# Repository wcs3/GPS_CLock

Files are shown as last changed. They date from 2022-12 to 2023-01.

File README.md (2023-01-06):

# GPS_CLock

A device that displays time and date on 7-segment displays in ISO8601 format.

Features:
 - Retrieves accurate time from GPS satellites
 - Displays time in compliance with ISO8601
 - Powered from a rechargeable battery for portable usage
 - Charges from a power delivery capable USB Type-C port

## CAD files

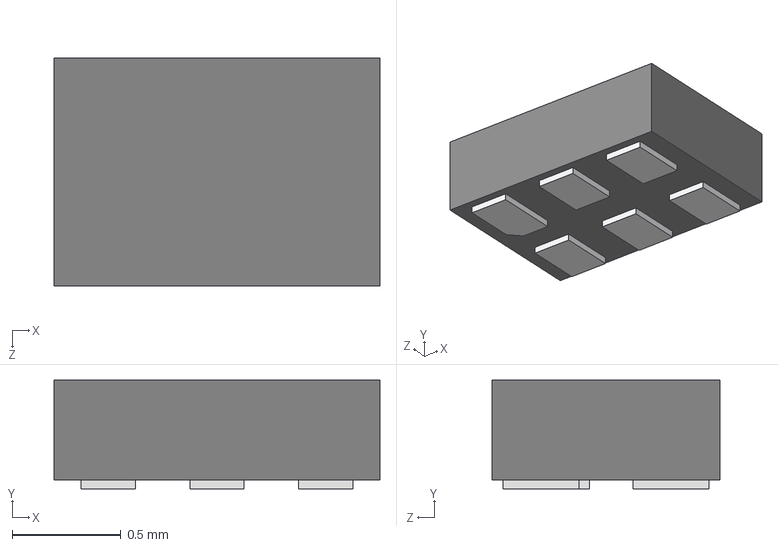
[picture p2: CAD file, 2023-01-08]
kicad/3d/SOT886.step
1.50 x 0.5 x 1.05 mm

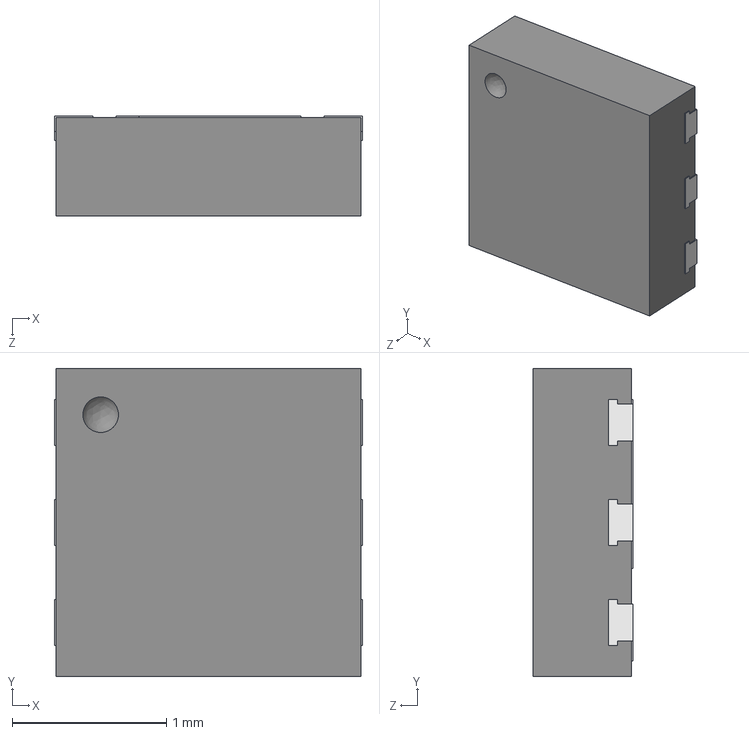
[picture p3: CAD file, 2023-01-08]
kicad/3d/User Library-PMPB95ENEA.STEP
2.00 x 2.00 x 0.65 mm

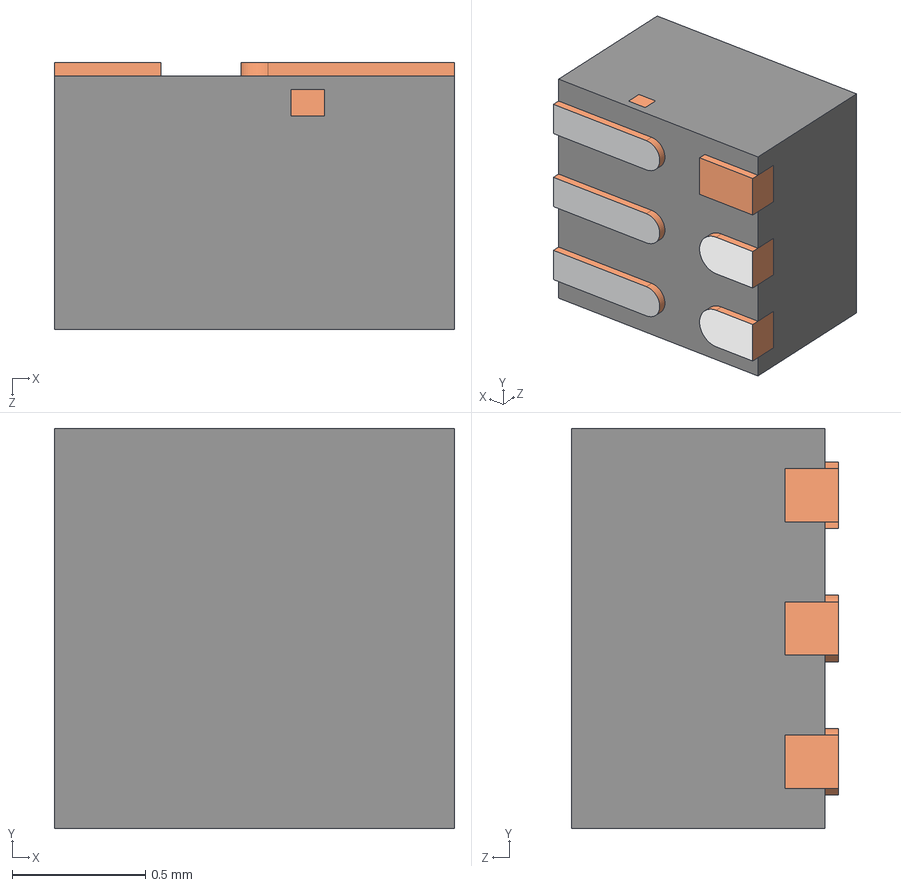
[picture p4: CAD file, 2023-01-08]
kicad/3d/VSON-HR-6.STEP
1.50 x 1.50 x 1.00 mm
BODY-SON
FRAME-DMQ0006A

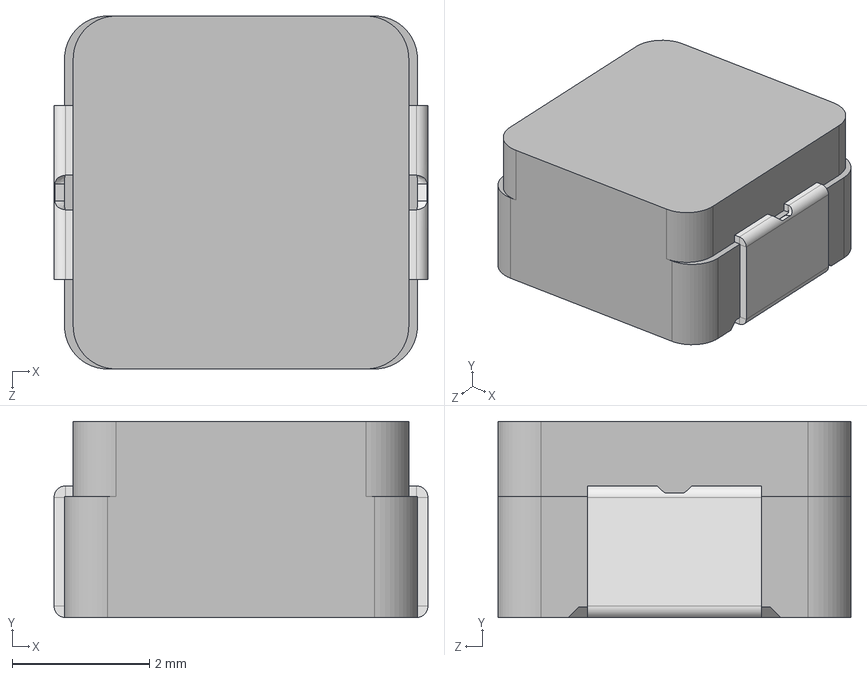
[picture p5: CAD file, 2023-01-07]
kicad/3d/IHLP2020CZ.STEP
5.45 x 2.86 x 5.15 mm

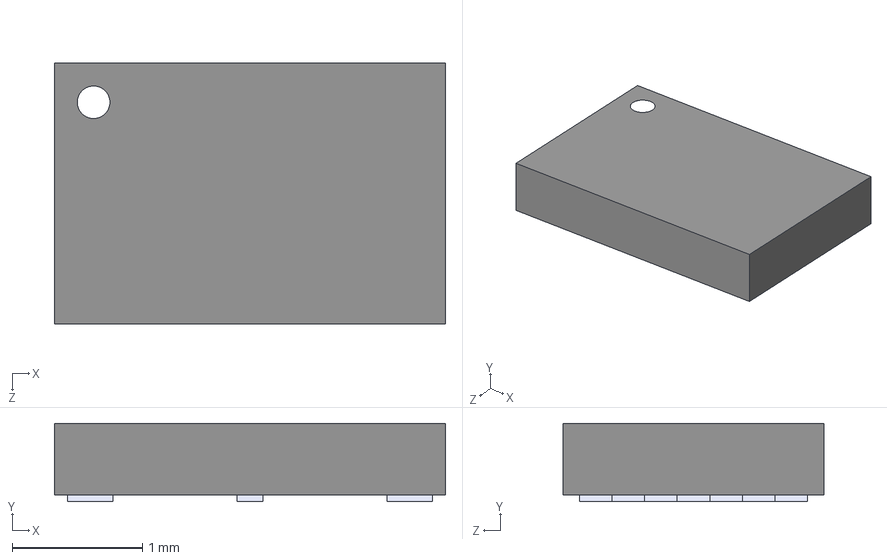
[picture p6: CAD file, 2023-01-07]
kicad/3d/W25Q16JVUXIQ.STEP
3.00 x 0.6 x 2.00 mm

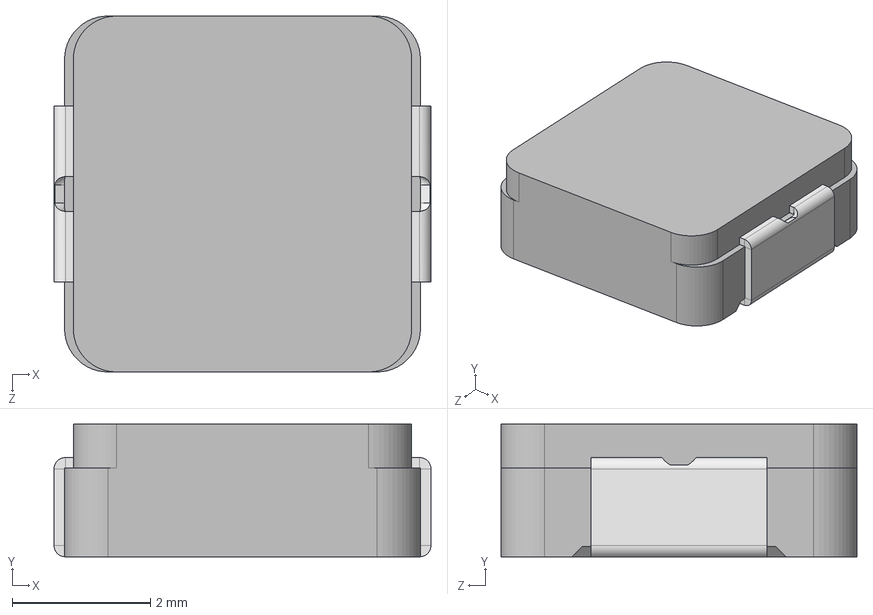
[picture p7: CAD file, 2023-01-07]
kicad/3d/IHLP2020BZ.STEP
5.45 x 1.92 x 5.15 mm

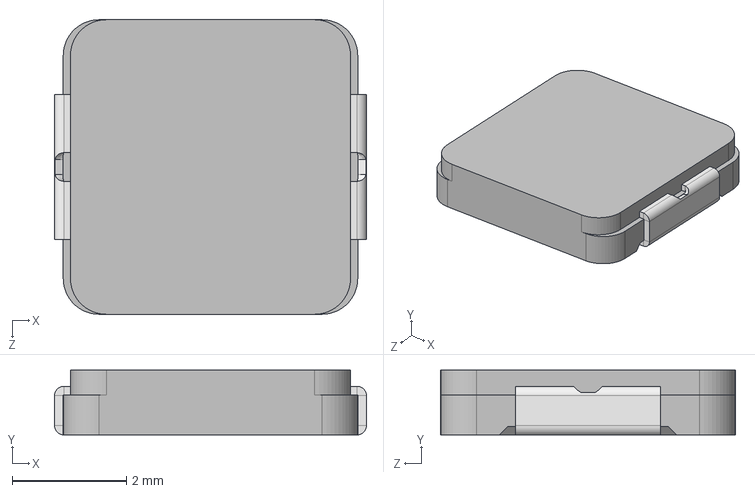
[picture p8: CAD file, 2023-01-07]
kicad/3d/IHLP2020AB.STEP
5.45 x 1.14 x 5.15 mm

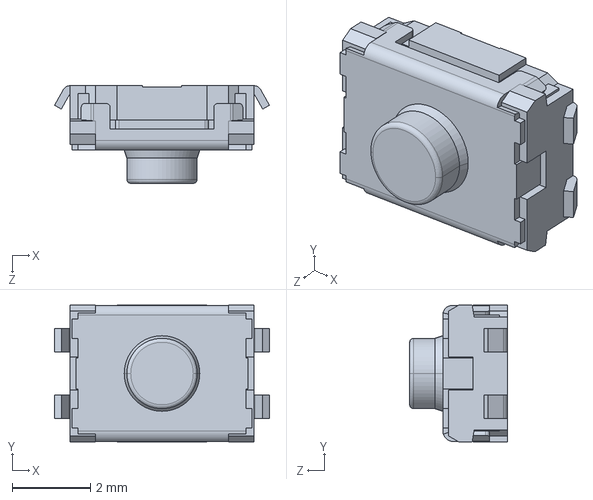
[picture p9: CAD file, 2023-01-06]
kicad/3d/EVQ-P2-H02B_K02Q+3P202K.STEP
5.50 x 3.50 x 2.50 mm

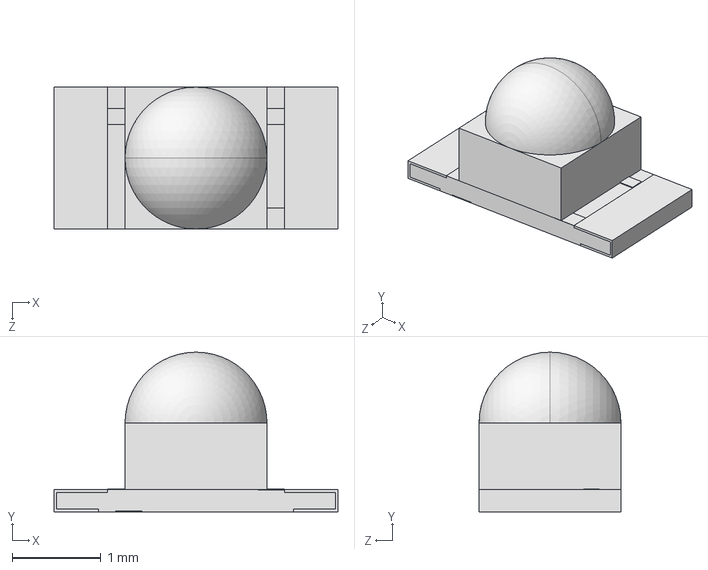
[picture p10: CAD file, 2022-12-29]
kicad/3d/APTD3216.STEP
3.20 x 1.80 x 1.60 mm

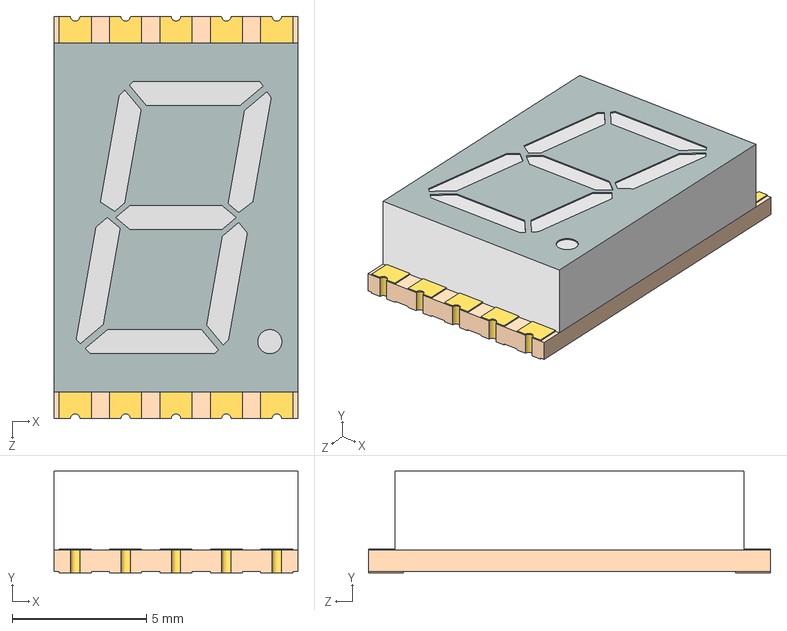
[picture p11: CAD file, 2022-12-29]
kicad/3d/ACSX04-41.STEP
9.10 x 3.80 x 15.0 mm

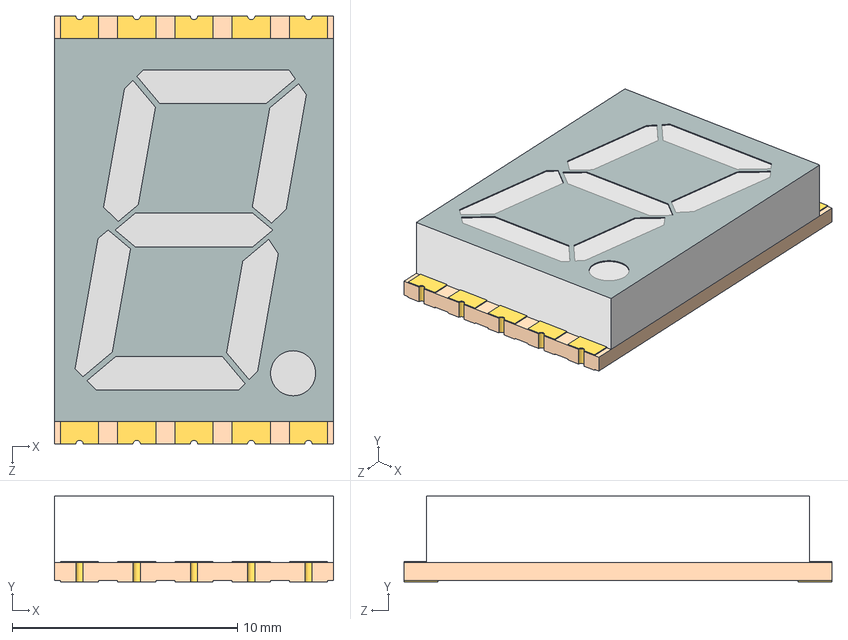
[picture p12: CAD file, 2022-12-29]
kicad/3d/ACSX56-41.STEP
12.4 x 3.80 x 19.0 mm

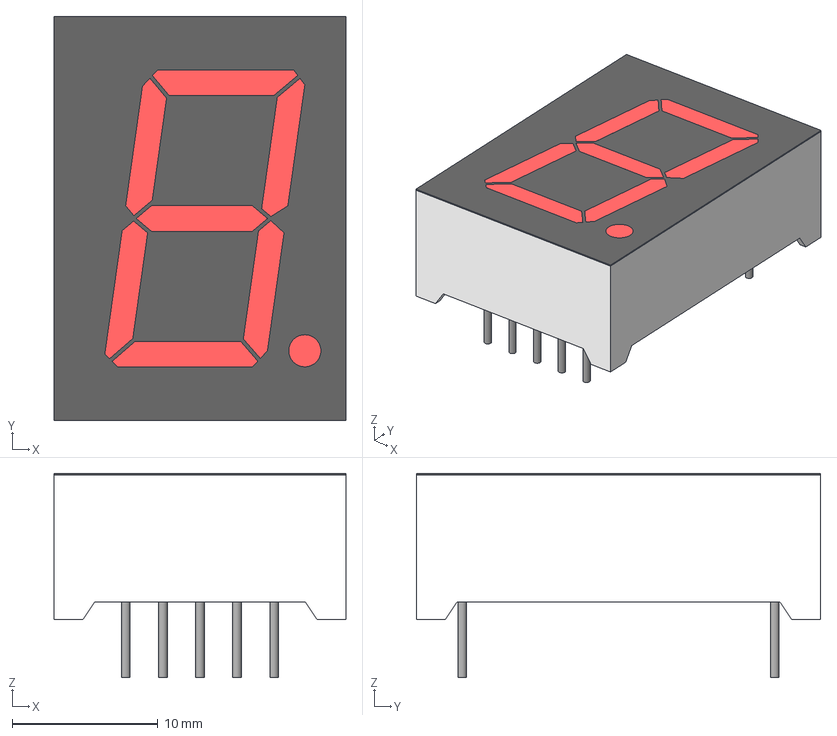
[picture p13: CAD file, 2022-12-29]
kicad/3d/7 seg 0,8 inch.step
20.0 x 27.7 x 14.0 mm

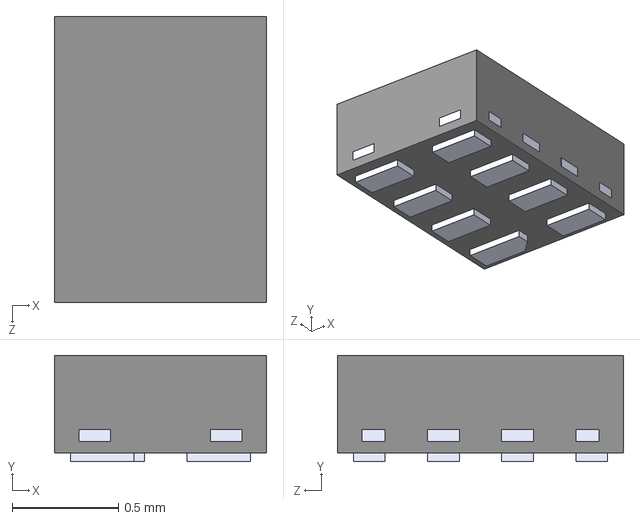
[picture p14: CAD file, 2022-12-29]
kicad/3d/74LVC3G17GS_115.step
1.00 x 0.5 x 1.35 mm

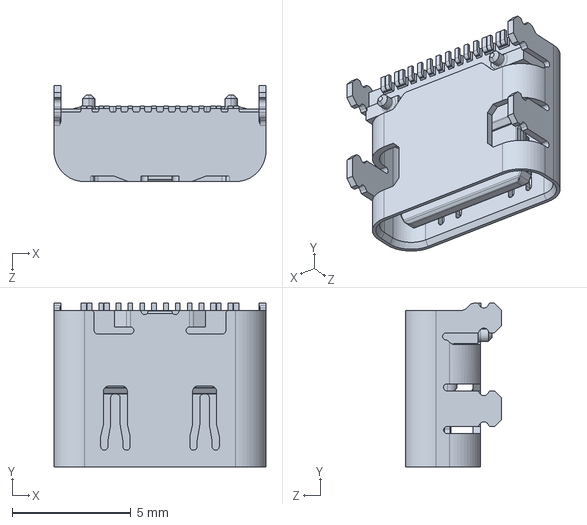
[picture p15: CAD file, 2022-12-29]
kicad/3d/K3D-DX07S016JA1-V1_JAE_Proprietary.STEP
8.94 x 6.90 x 4.06 mm

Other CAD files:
kicad/3d/MAX-M8C-0-10--3DModel-STEP-56544.STEP
kicad/3d/ACPSX04-41.STEP
kicad/3d/TactileSw6x6x4.3.STEP
kicad/3d/1-1734839-6.step
kicad/3d/14-Segment_0.4in_SMD.step
kicad/3d/7-Segment_0.4in_SMD.step
kicad/3d/84592VEML7700.stp
kicad/3d/ACSX08-51.STEP
kicad/3d/DFE201610P-R47M=P2.STEP
kicad/3d/EVQP4-HB3B_KB3Q_MB3K.STEP
kicad/3d/FH35-21S-0.3SHW.stp
kicad/3d/MS860702BA01-50--3DModel-STEP-1.STEP
kicad/3d/PSON30P120X100X35-8N.step

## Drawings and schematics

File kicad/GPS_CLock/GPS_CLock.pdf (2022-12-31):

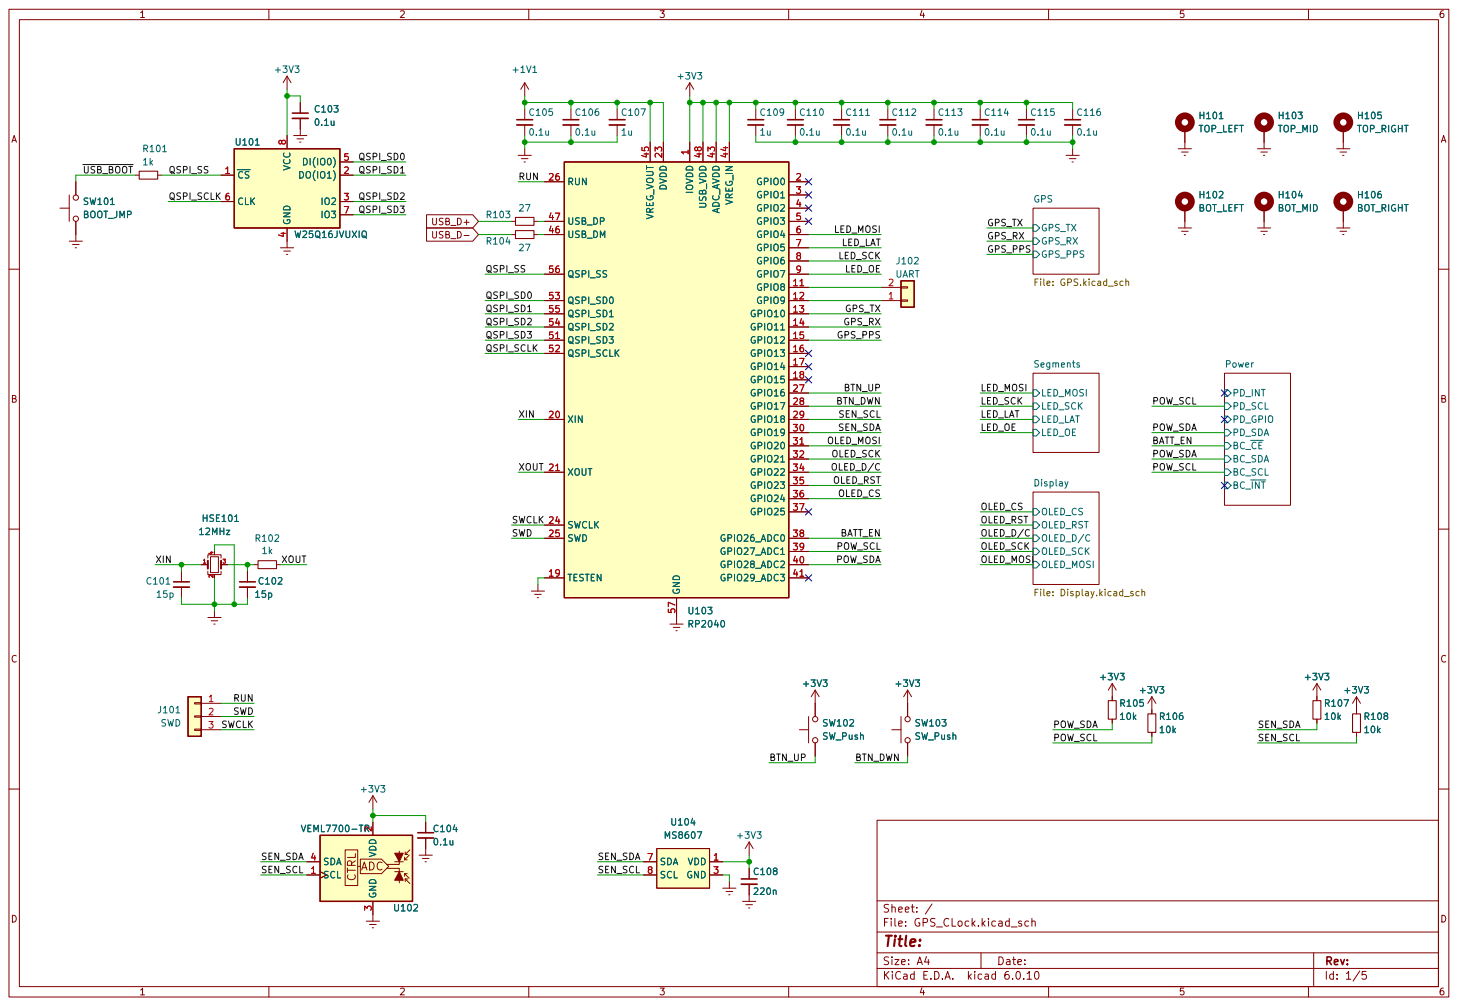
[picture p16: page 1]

1 GPIO8 11 GPIO9 12 GPIO10 13 GPIO11 14 GPIO12 15 GPIO13 16 GPIO14 17 GPIO15 18 TESTEN 19 GPIO0 2 XIN 20 XOUT 21 DVDD 23 SWCLK 24 SWD 25 RUN 26 GPIO16 27 GPIO17 28 GPIO18 29 GPIO1 3 GPIO19 30 GPIO20 31 GPIO21 32 GPIO22 34 GPIO23 35 GPIO24 36 GPIO25 37 GPIO26_ADC0 38 GPIO27_ADC1 39 GPIO2 4 GPIO28_ADC2 40 GPIO29_ADC3 41 ADC_AVDD 43 VREG_IN 44 VREG_VOUT 45 USB_DM 46 USB_DP 47 USB_VDD 48 GPIO3 5 QSPI_SD3 51 QSPI_SCLK 52 QSPI_SD0 53 QSPI_SD2 54 QSPI_SD1 55 QSPI_SS 56 GND 57 GPIO4 6 GPIO5 7 GPIO6 8 GPIO7 9 C102

1 GPIO8 11 GPIO9 12 GPIO10 13 GPIO11 14 GPIO12 15 GPIO13 16 GPIO14 17 GPIO15 18 TESTEN 19 GPIO0 2 XIN 20 XOUT 21 DVDD 23 SWCLK 24 SWD 25 RUN 26 GPIO16 27 GPIO17 28 GPIO18 29 GPIO1 3 GPIO19 30 GPIO20 31 GPIO21 32 GPIO22 34 GPIO23 35 GPIO24 36 GPIO25 37 GPIO26_ADC0 38 GPIO27_ADC1 39 GPIO2 4 GPIO28_ADC2 40 GPIO29_ADC3 41 ADC_AVDD 43 VREG_IN 44 VREG_VOUT 45 USB_DM 46 USB_DP 47 USB_VDD 48 GPIO3 5 QSPI_SD3 51 QSPI_SCLK 52 QSPI_SD0 53 QSPI_SD2 54 QSPI_SD1 55 QSPI_SS 56 GND 57 GPIO4 6 GPIO5 7 GPIO6 8 GPIO7 9 U103 RP2040

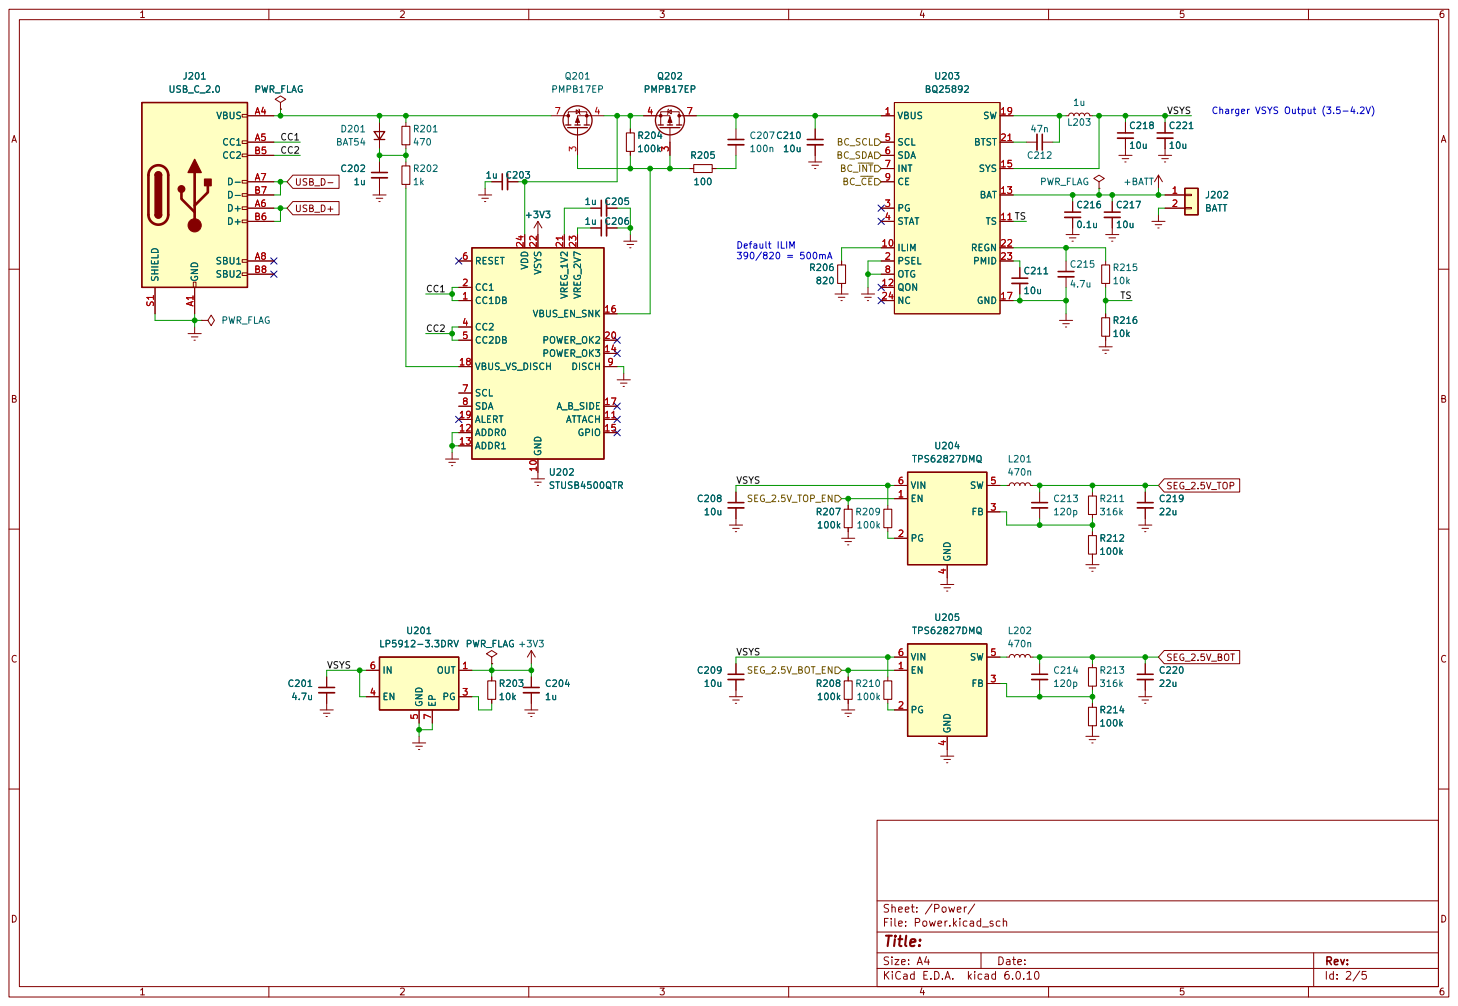
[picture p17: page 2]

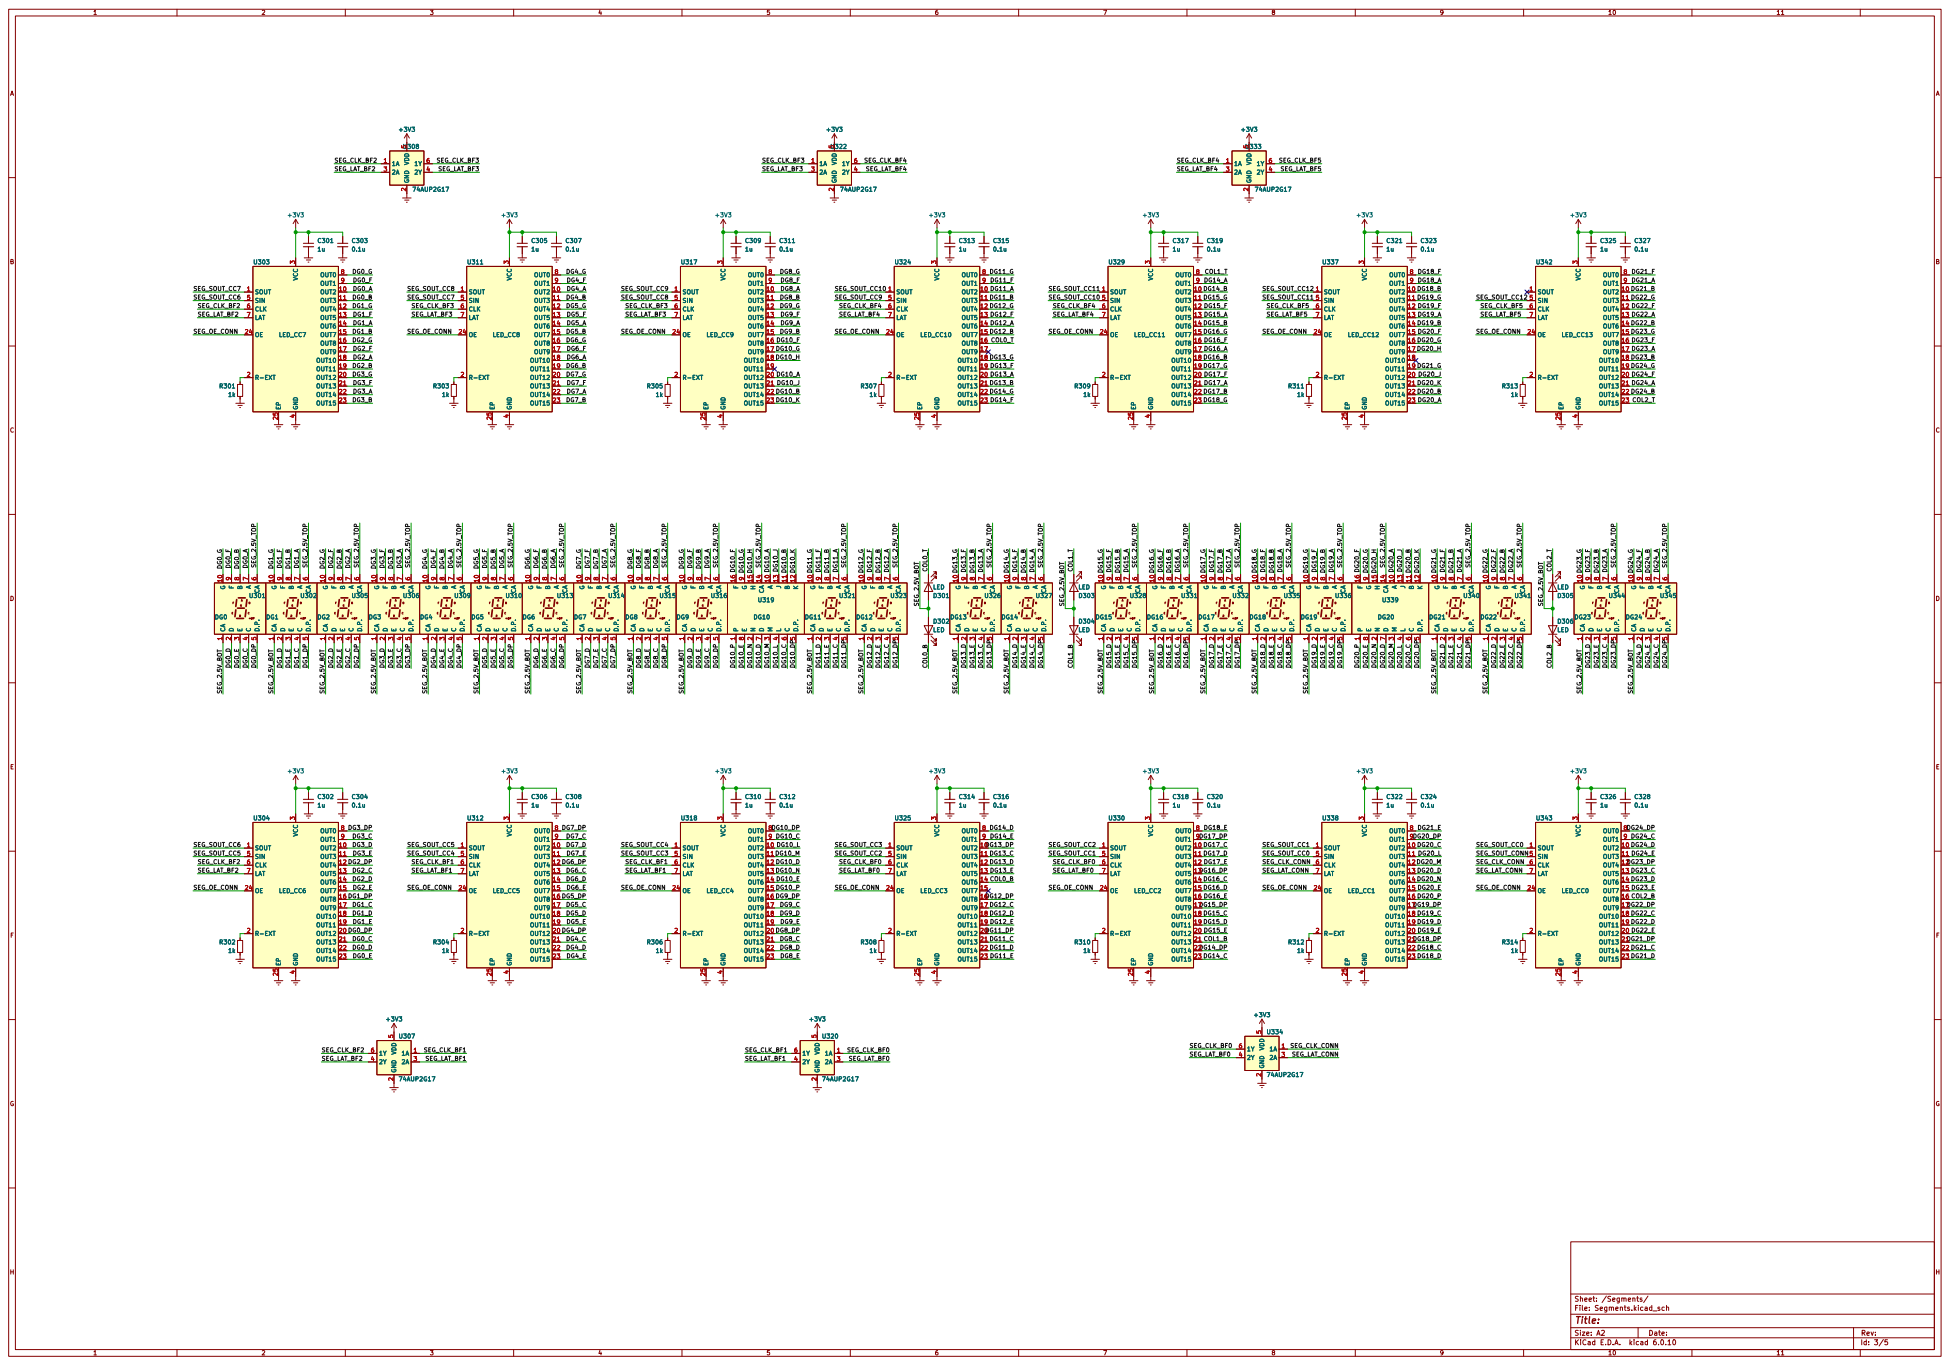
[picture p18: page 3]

9 U301 DG0 SOUT 1 OUT2 10 OUT3 11 OUT4 12 OUT5 13 OUT6 14 OUT7 15 OUT8 16 OUT9 17 OUT10 18 OUT11 19 R-EXT 2 OUT12 20 OUT13 21 OUT14 22 OUT15 23 OE 24 EP 25 VCC

9 U316 DG9SOUT 1 OUT2 10 OUT3 11 OUT4 12 OUT5 13 OUT6 14 OUT7 15 OUT8 16 OUT9 17 OUT10 18 OUT11 19 R-EXT 2 OUT12 20 OUT13 21 OUT14 22 OUT15 23 OE 24 EP 25 VCC

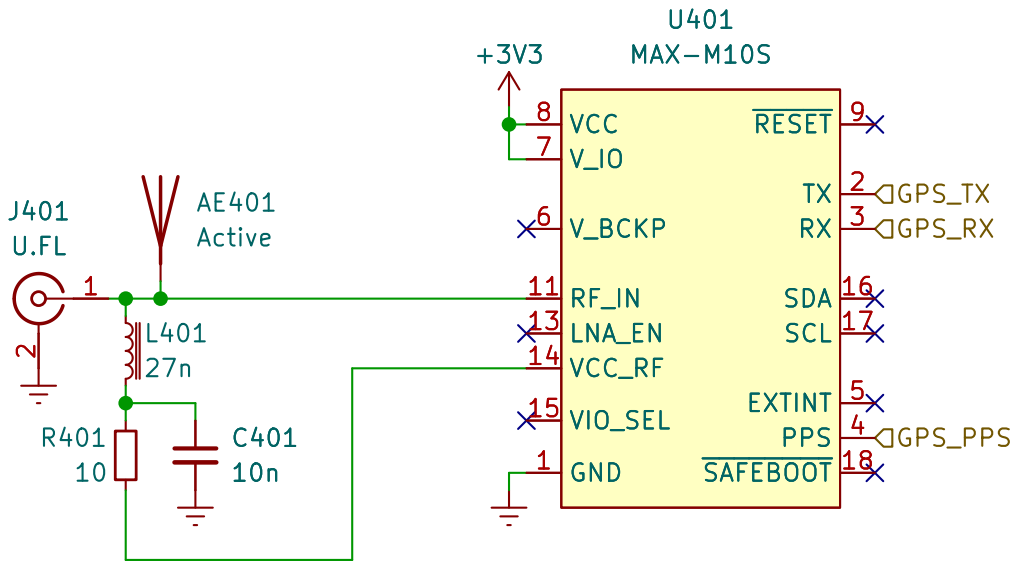
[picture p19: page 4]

File: GPS.kicad_sch Sheet: /GPS/
Id: 5/5 Title:

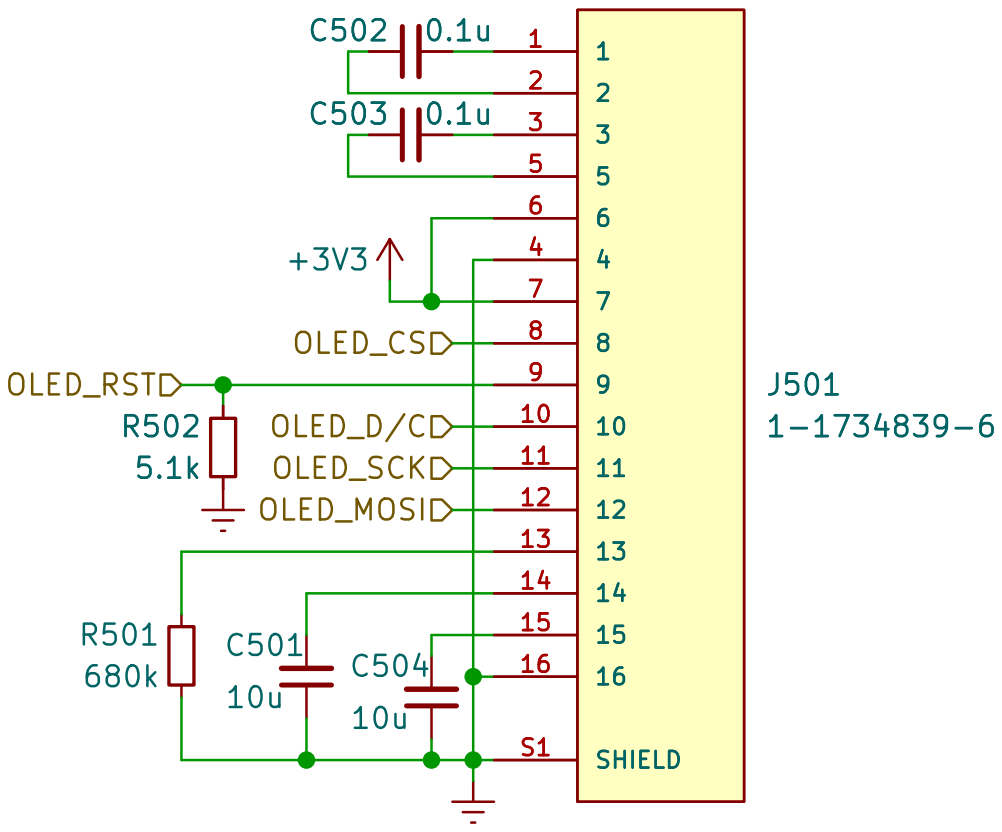
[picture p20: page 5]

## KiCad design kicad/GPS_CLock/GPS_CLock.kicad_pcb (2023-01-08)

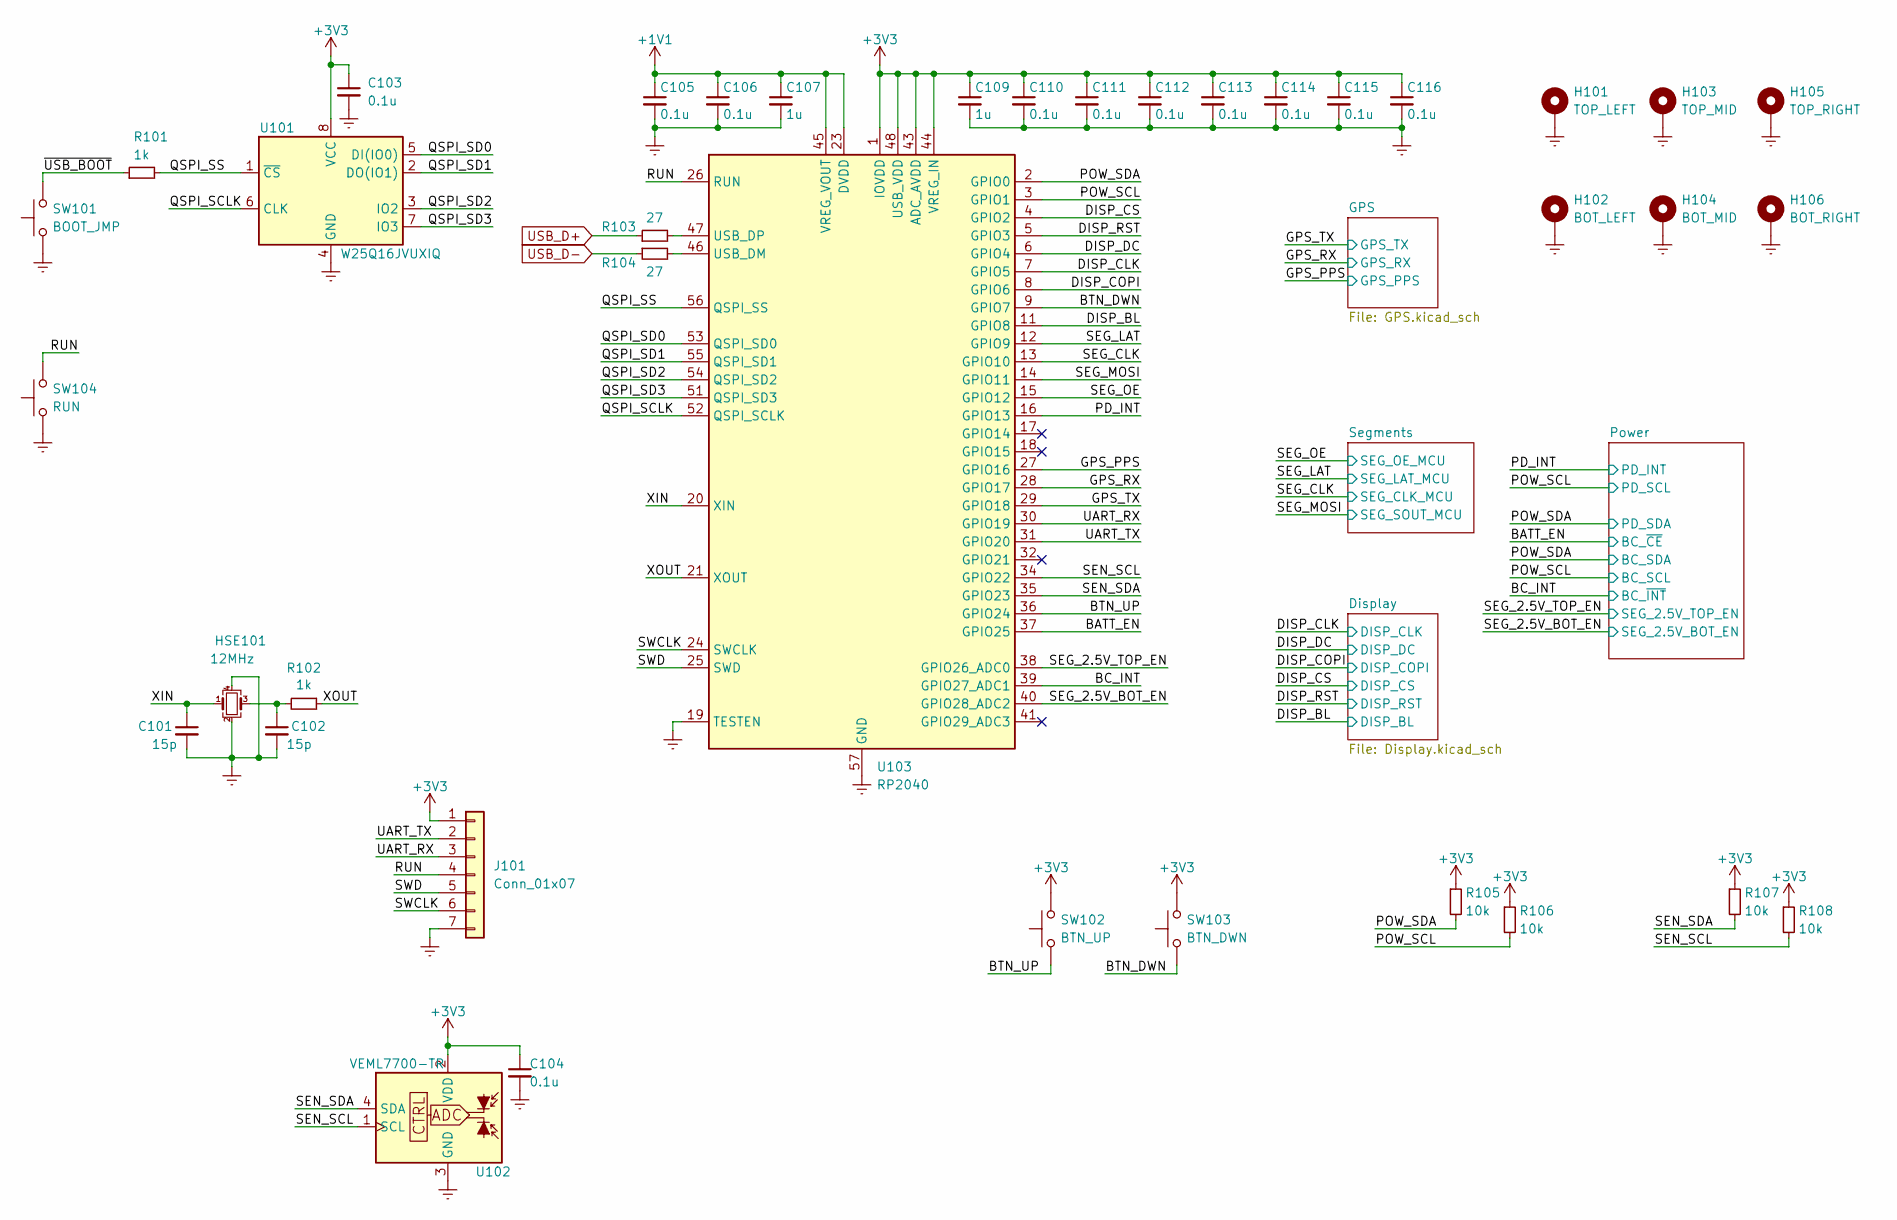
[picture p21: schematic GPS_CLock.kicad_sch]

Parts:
C101, C102: 15p; C_0402_1005Metric
C103, C104, C105, C106, C110, C111, C112, C113, C114, C115, C116: 0.1u; C_0402_1005Metric
C107, C109: 1u; C_0402_1005Metric
H101: TOP_LEFT; MountingHole_3.2mm_M3_DIN965_Pad
H102: BOT_LEFT; MountingHole_3.2mm_M3_DIN965_Pad
H103: TOP_MID; MountingHole_3.2mm_M3_DIN965_Pad
H104: BOT_MID; MountingHole_3.2mm_M3_DIN965_Pad
H105: TOP_RIGHT; MountingHole_3.2mm_M3_DIN965_Pad
H106: BOT_RIGHT; MountingHole_3.2mm_M3_DIN965_Pad
HSE101: 12MHz; Crystal_SMD_3225-4Pin_3.2x2.5mm
J101: Conn_01x07; PinHeader_1x07_P1.27mm_Vertical
R101, R102: 1k; R_0402_1005Metric
R103, R104: 27; R_0402_1005Metric
R105, R106, R107, R108: 10k; R_0402_1005Metric
SW101: BOOT_JMP; SW_SPST_EVQP2
SW102: BTN_UP; SW_SPST_EVQP2
SW103: BTN_DWN; SW_SPST_EVQP2
SW104: RUN; SW_SPST_EVQP2
U101: W25Q16JVUXIQ; WINBOND_USON-8_2x3mm
U102: VEML7700-TR; VEML7700
U103: RP2040; QFN-56-1EP_7x7mm_P0.4mm_EP3.2x3.2mm

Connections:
+1V1: C105.1, C106.1, C107.1, U103.23 (DVDD), U103.45 (VREG_VOUT), U103.50 (DVDD)
+3V3: C103.1, C104.1, C109.1, C110.1, C111.1, C112.1, C113.1, C114.1, C115.1, C116.1, J101.1, R105.1, R106.1, R107.1, R108.1, SW102.1, SW103.1, U101.8 (VCC), U102.2 (VDD), U103.1 (IOVDD), U103.10 (IOVDD), U103.22 (IOVDD), U103.33 (IOVDD), U103.42 (IOVDD), U103.43 (ADC_AVDD), U103.44 (VREG_IN), U103.48 (USB_VDD), U103.49 (IOVDD); also elsewhere on the board
/BATT_EN: U103.37 (GPIO25); also elsewhere on the board
/BC_INT: U103.39 (GPIO27_ADC1); also elsewhere on the board
/BTN_DWN: SW103.2, U103.9 (GPIO7)
/BTN_UP: SW102.2, U103.36 (GPIO24)
/DISP_BL: U103.11 (GPIO8); also elsewhere on the board
/DISP_CLK: U103.7 (GPIO5); also elsewhere on the board
/DISP_COPI: U103.8 (GPIO6); also elsewhere on the board
/DISP_CS: U103.4 (GPIO2); also elsewhere on the board
/DISP_DC: U103.6 (GPIO4); also elsewhere on the board
/DISP_RST: U103.5 (GPIO3); also elsewhere on the board
/GPS_PPS: U103.27 (GPIO16); also elsewhere on the board
/GPS_RX: U103.28 (GPIO17); also elsewhere on the board
/GPS_TX: U103.29 (GPIO18); also elsewhere on the board
/PD_INT: U103.16 (GPIO13); also elsewhere on the board
/POW_SCL: R106.2, U103.3 (GPIO1); also elsewhere on the board
/POW_SDA: R105.2, U103.2 (GPIO0); also elsewhere on the board
/QSPI_SCLK: U101.6 (CLK), U103.52 (QSPI_SCLK)
/QSPI_SD0: U101.5 (DI(IO0)), U103.53 (QSPI_SD0)
/QSPI_SD1: U101.2 (DO(IO1)), U103.55 (QSPI_SD1)
/QSPI_SD2: U101.3 (IO2), U103.54 (QSPI_SD2)
/QSPI_SD3: U101.7 (IO3), U103.51 (QSPI_SD3)
/QSPI_SS: R101.2, U101.1 (~CS), U103.56 (QSPI_SS)
/RUN: J101.4, SW104.1, U103.26 (RUN)
/SEG_2.5V_BOT_EN: U103.40 (GPIO28_ADC2); also elsewhere on the board
/SEG_2.5V_TOP_EN: U103.38 (GPIO26_ADC0); also elsewhere on the board
/SEG_CLK: U103.13 (GPIO10); also elsewhere on the board
/SEG_LAT: U103.12 (GPIO9); also elsewhere on the board
/SEG_MOSI: U103.14 (GPIO11); also elsewhere on the board
/SEG_OE: U103.15 (GPIO12); also elsewhere on the board
/SEN_SCL: R108.2, U102.1 (SCL), U103.34 (GPIO22)
/SEN_SDA: R107.2, U102.4 (SDA), U103.35 (GPIO23)
/SWCLK: J101.6, U103.24 (SWCLK)
/SWD: J101.5, U103.25 (SWD)
/UART_RX: J101.3, U103.30 (GPIO19)
/UART_TX: J101.2, U103.31 (GPIO20)
/XIN: C101.1, HSE101.1, U103.20 (XIN)
/XOUT: R102.1, U103.21 (XOUT)
/~USB_BOOT: R101.1, SW101.1
Earth: C101.2, C102.2, C103.2, C104.2, C105.2, C106.2, C107.2, C109.2, C110.2, C111.2, C112.2, C113.2, C114.2, C115.2, C116.2, H101.1, H102.1, H103.1, H104.1, H105.1, H106.1, HSE101.2, HSE101.4, J101.7, SW101.2, SW104.2, U101.4 (GND), U102.3 (GND), U103.19 (TESTEN), U103.57 (GND); also elsewhere on the board
unnamed: C102.1, HSE101.3, R102.2
unnamed: R103.2, U103.47 (USB_DP)
unnamed: R104.2, U103.46 (USB_DM)
USB_D+: R103.1; also elsewhere on the board
USB_D-: R104.1; also elsewhere on the board

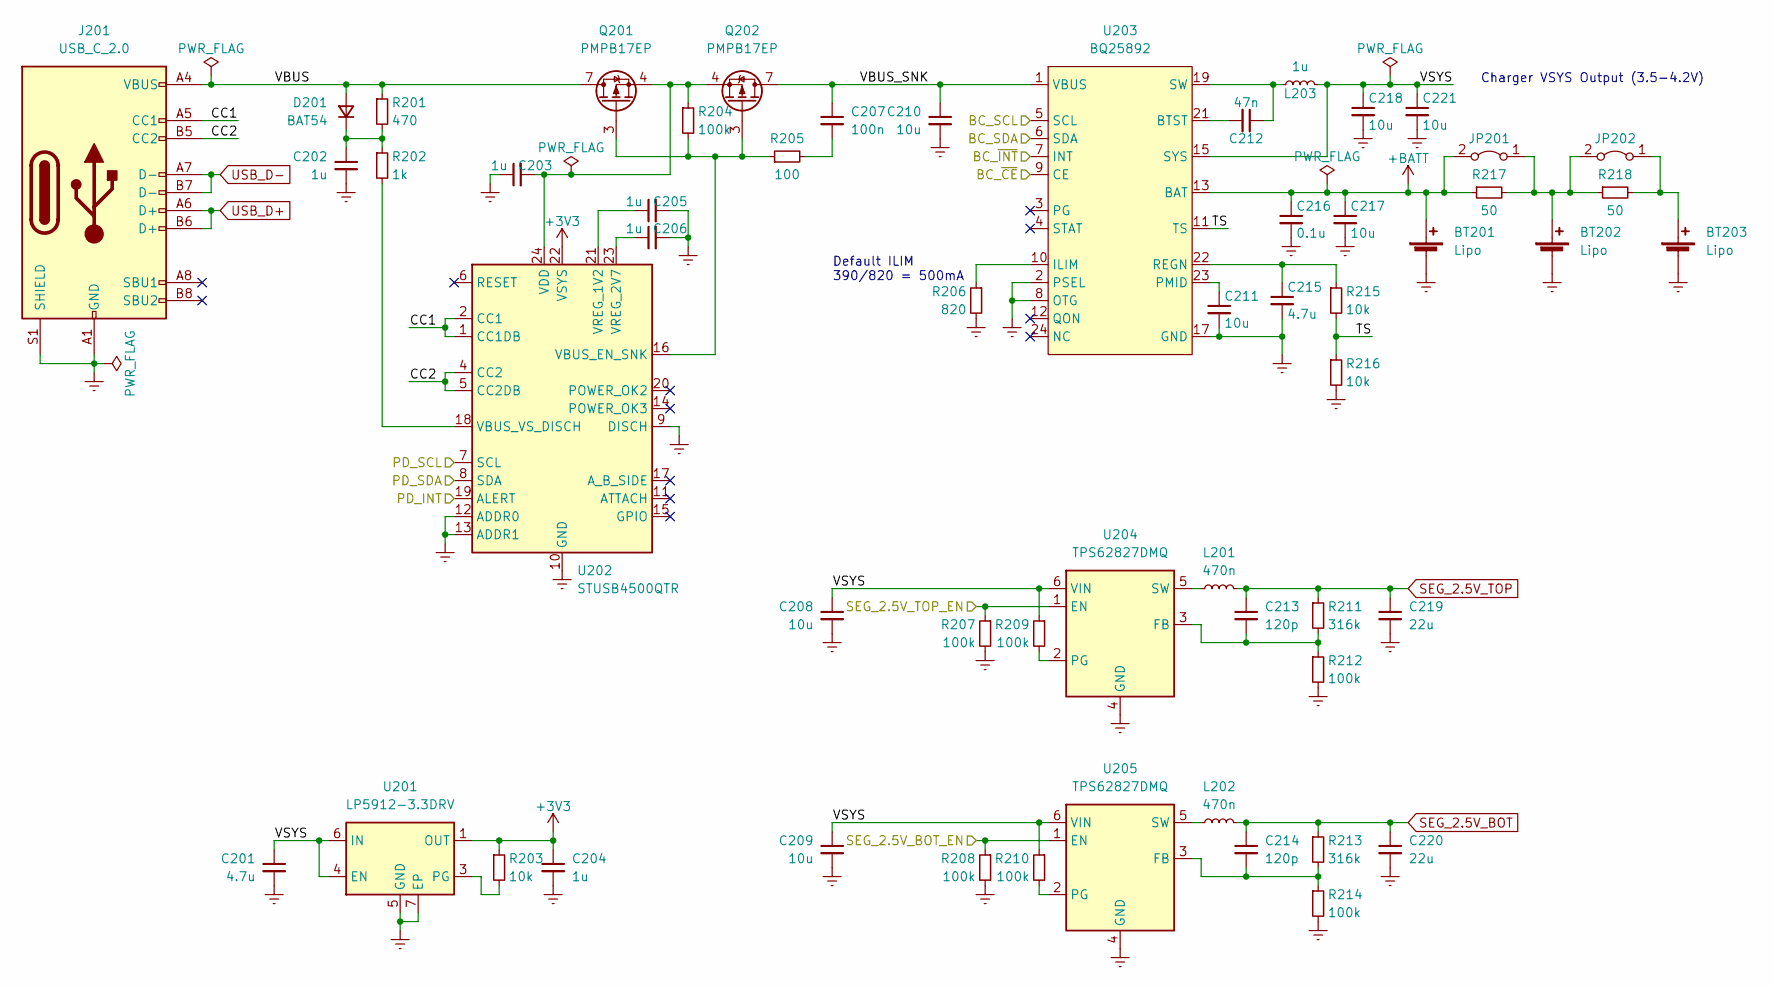
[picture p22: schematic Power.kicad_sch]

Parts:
BT201, BT202, BT203: Lipo; JST_PH_S2B-PH-K_1x02_P2.00mm_Horizontal
C201: 4.7u; C_0603_1608Metric
C202, C203, C204, C205, C206: 1u; C_0402_1005Metric
C207: 100n; C_0402_1005Metric
C208, C209, C217, C218, C221: 10u; C_0603_1608Metric
C210, C211: 10u; C_0402_1005Metric
C212: 47n; C_0402_1005Metric
C213, C214: 120p; C_0402_1005Metric
C215: 4.7u; C_0402_1005Metric
C216: 0.1u; C_0402_1005Metric
C219, C220: 22u; C_0603_1608Metric
D201: BAT54; D_SOD-323
J201: USB_C_2.0; USB_C_Receptacle_JAE_DX07S016JA1R1500
JP201, JP202: Jumper_2_Bridged; PinHeader_1x02_P2.54mm_Horizontal
L201, L202: 470n; L_DFE201610
L203: 1u; L_Vishay_IHLP-2020
Q201, Q202: PMPB17EP; NXP_DFN6_2.0x2.0mm 2xEp
R201: 470; R_0402_1005Metric
R202: 1k; R_0402_1005Metric
R203, R215, R216: 10k; R_0402_1005Metric
R204, R207, R208, R209, R210, R212, R214: 100k; R_0402_1005Metric
R205: 100; R_0402_1005Metric
R206: 820; R_0402_1005Metric
R211, R213: 316k; R_0402_1005Metric
R217, R218: 50; R_1206_3216Metric
U201: LP5912-3.3DRV; WSON-6-1EP_2x2mm_P0.65mm_EP1x1.6mm_ThermalVias
U202: STUSB4500QTR; QFN-24-1EP_4x4mm_P0.5mm_EP2.7x2.7mm
U203: BQ25892; Texas_S-PWQFN-N24_EP2.7x2.7mm
U204, U205: TPS62827DMQ; VSON-6-HR

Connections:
+3V3: C204.1, R203.1, U201.1 (OUT), U202.22 (VSYS); also elsewhere on the board
+BATT: BT201.1 (+), C216.1, C217.1, JP201.2 (B), R217.1, U203.13 (BAT), U203.14 (BAT)
/BATT_EN: U203.9 (CE); also elsewhere on the board
/BC_INT: U203.7 (INT); also elsewhere on the board
/PD_INT: U202.19 (ALERT); also elsewhere on the board
/POW_SCL: U202.7 (SCL), U203.5 (SCL); also elsewhere on the board
/POW_SDA: U202.8 (SDA), U203.6 (SDA); also elsewhere on the board
/Power/CC1: J201.A5 (CC1), U202.1 (CC1DB), U202.2 (CC1)
/Power/CC2: J201.B5 (CC2), U202.4 (CC2), U202.5 (CC2DB)
/Power/TS: R215.2, R216.1, U203.11 (TS)
/Power/VBUS: D201.2 (A), J201.A4 (VBUS), J201.A9 (VBUS), J201.B4 (VBUS), J201.B9 (VBUS), Q201.1 (D), Q201.2 (D), Q201.5 (D), Q201.6 (D), Q201.7 (D), R201.1
/Power/VBUS_SNK: C207.1, C210.1, Q202.1 (D), Q202.2 (D), Q202.5 (D), Q202.6 (D), Q202.7 (D), U203.1 (VBUS)
/Power/VSYS: C201.1, C208.1, C209.1, C218.1, C221.1, L203.2, R209.1, R210.1, U201.4 (EN), U201.6 (IN), U203.15 (SYS), U203.16 (SYS), U204.6 (VIN), U205.6 (VIN)
/SEG_2.5V_BOT_EN: R208.1, U205.1 (EN); also elsewhere on the board
/SEG_2.5V_TOP_EN: R207.1, U204.1 (EN); also elsewhere on the board
Earth: BT201.2 (-), BT202.2 (-), BT203.2 (-), C201.2, C202.2, C203.1, C204.2, C205.2, C206.2, C208.2, C209.2, C210.2, C211.2, C215.2, C216.2, C217.2, C218.2, C219.2, C220.2, C221.2, J201.A1 (GND), J201.A12 (GND), J201.B1 (GND), J201.B12 (GND), J201.S1 (SHIELD), R206.2, R207.2, R208.2, R212.2, R214.2, R216.2, U201.5 (GND), U201.7 (EP), U202.9 (DISCH), U202.10 (GND), U202.12 (ADDR0), U202.13 (ADDR1), U202.25 (GND), U203.2 (PSEL), U203.8 (OTG), U203.17 (GND), U203.18 (GND), U203.25 (GND), U204.4 (GND), U205.4 (GND); also elsewhere on the board
unnamed: BT202.1 (+), JP201.1 (A), JP202.2 (B), R217.2, R218.1
unnamed: BT203.1 (+), JP202.1 (A), R218.2
unnamed: C202.1, D201.1 (K), R201.2, R202.1
unnamed: C203.2, Q201.4 (S), Q201.8 (S), Q202.4 (S), Q202.8 (S), R204.1, U202.24 (VDD)
unnamed: C205.1, U202.21 (VREG_1V2)
unnamed: C206.1, U202.23 (VREG_2V7)
unnamed: C207.2, R205.2
unnamed: C211.1, U203.23 (PMID)
unnamed: C212.1, L203.1, U203.19 (SW), U203.20 (SW)
unnamed: C212.2, U203.21 (BTST)
unnamed: C213.2, R211.2, R212.1, U204.3 (FB)
unnamed: C214.2, R213.2, R214.1, U205.3 (FB)
unnamed: C215.1, R215.1, U203.22 (REGN)
unnamed: L201.1, U204.5 (SW)
unnamed: L202.1, U205.5 (SW)
unnamed: Q201.3 (G), Q202.3 (G), R204.2, R205.1, U202.16 (VBUS_EN_SNK)
unnamed: R202.2, U202.18 (VBUS_VS_DISCH)
unnamed: R203.2, U201.3 (PG)
unnamed: R206.1, U203.10 (ILIM)
unnamed: R209.2, U204.2 (PG)
unnamed: R210.2, U205.2 (PG)
SEG_2.5V_BOT: C214.1, C220.1, L202.2, R213.1; also elsewhere on the board
SEG_2.5V_TOP: C213.1, C219.1, L201.2, R211.1; also elsewhere on the board
USB_D+: J201.A6 (D+), J201.B6 (D+); also elsewhere on the board
USB_D-: J201.A7 (D-), J201.B7 (D-); also elsewhere on the board

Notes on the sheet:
Default ILIM 390/820 = 500mA
Charger VSYS Output (3.5-4.2V)

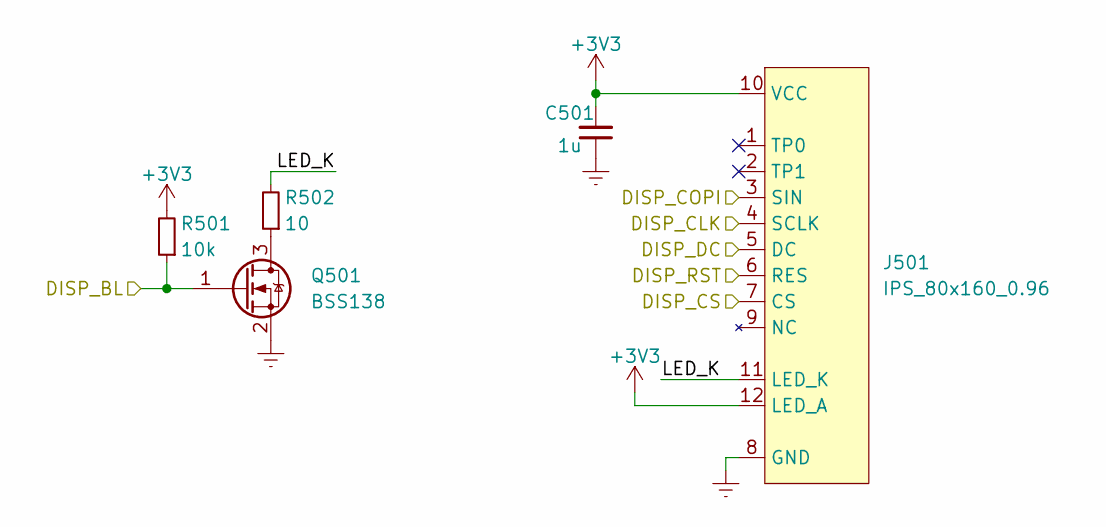
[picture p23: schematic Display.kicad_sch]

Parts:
C501: 1u; C_0402_1005Metric
J501: IPS_80x160_0.96; IPS_FPC-13
Q501: BSS138; SOT-23
R501: 10k; R_0402_1005Metric
R502: 10; R_0402_1005Metric

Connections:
+3V3: C501.2, J501.10 (VCC), J501.12 (LED_A), R501.2; also elsewhere on the board
/DISP_BL: Q501.1 (G), R501.1; also elsewhere on the board
/DISP_CLK: J501.4 (SCLK); also elsewhere on the board
/DISP_COPI: J501.3 (SIN); also elsewhere on the board
/DISP_CS: J501.7 (CS); also elsewhere on the board
/DISP_DC: J501.5 (DC); also elsewhere on the board
/DISP_RST: J501.6 (RES); also elsewhere on the board
/Display/LED_K: J501.11 (LED_K), R502.2
Earth: C501.1, J501.8 (GND), J501.13 (GND), Q501.2 (S); also elsewhere on the board
unnamed: Q501.3 (D), R502.1

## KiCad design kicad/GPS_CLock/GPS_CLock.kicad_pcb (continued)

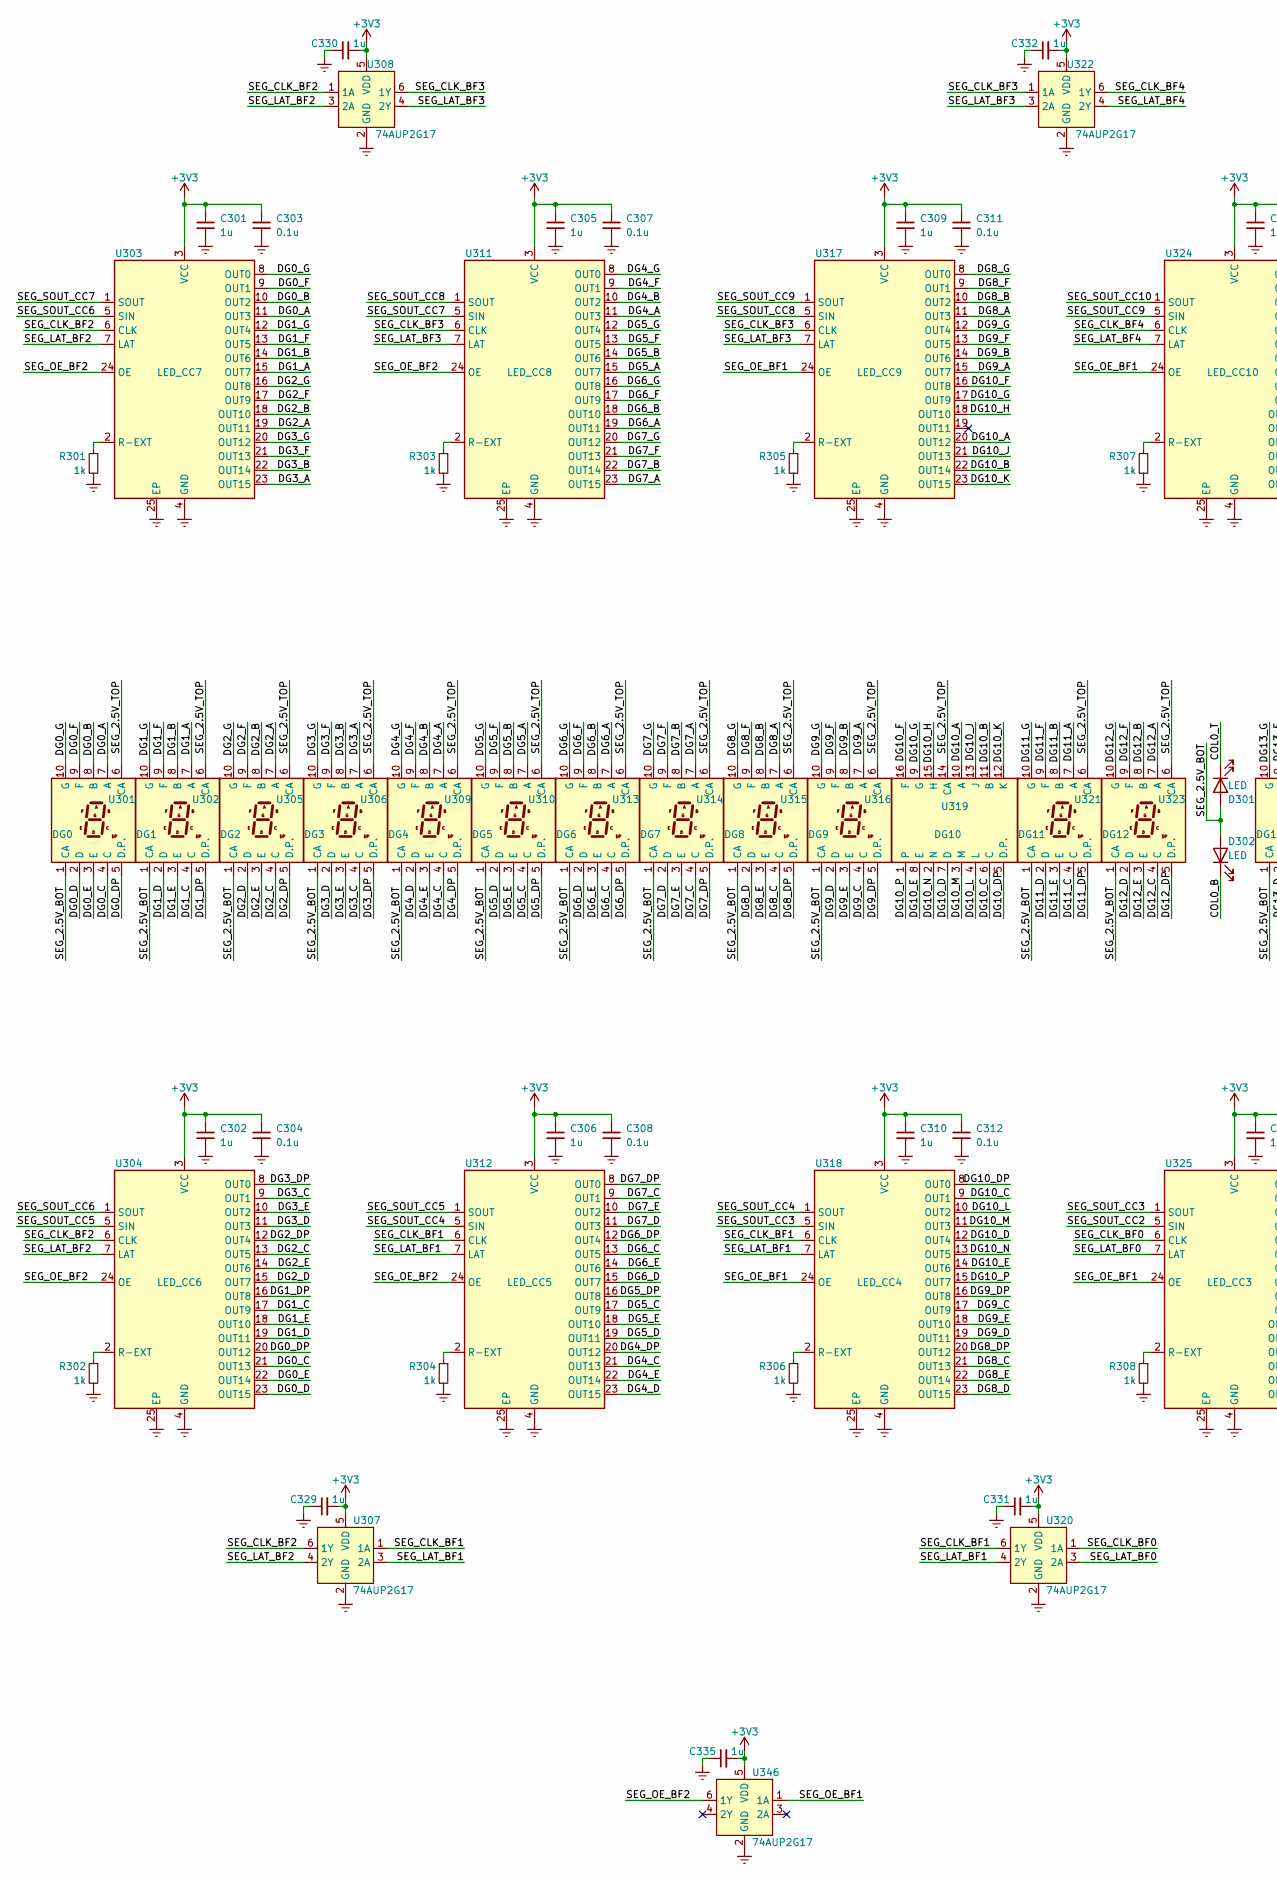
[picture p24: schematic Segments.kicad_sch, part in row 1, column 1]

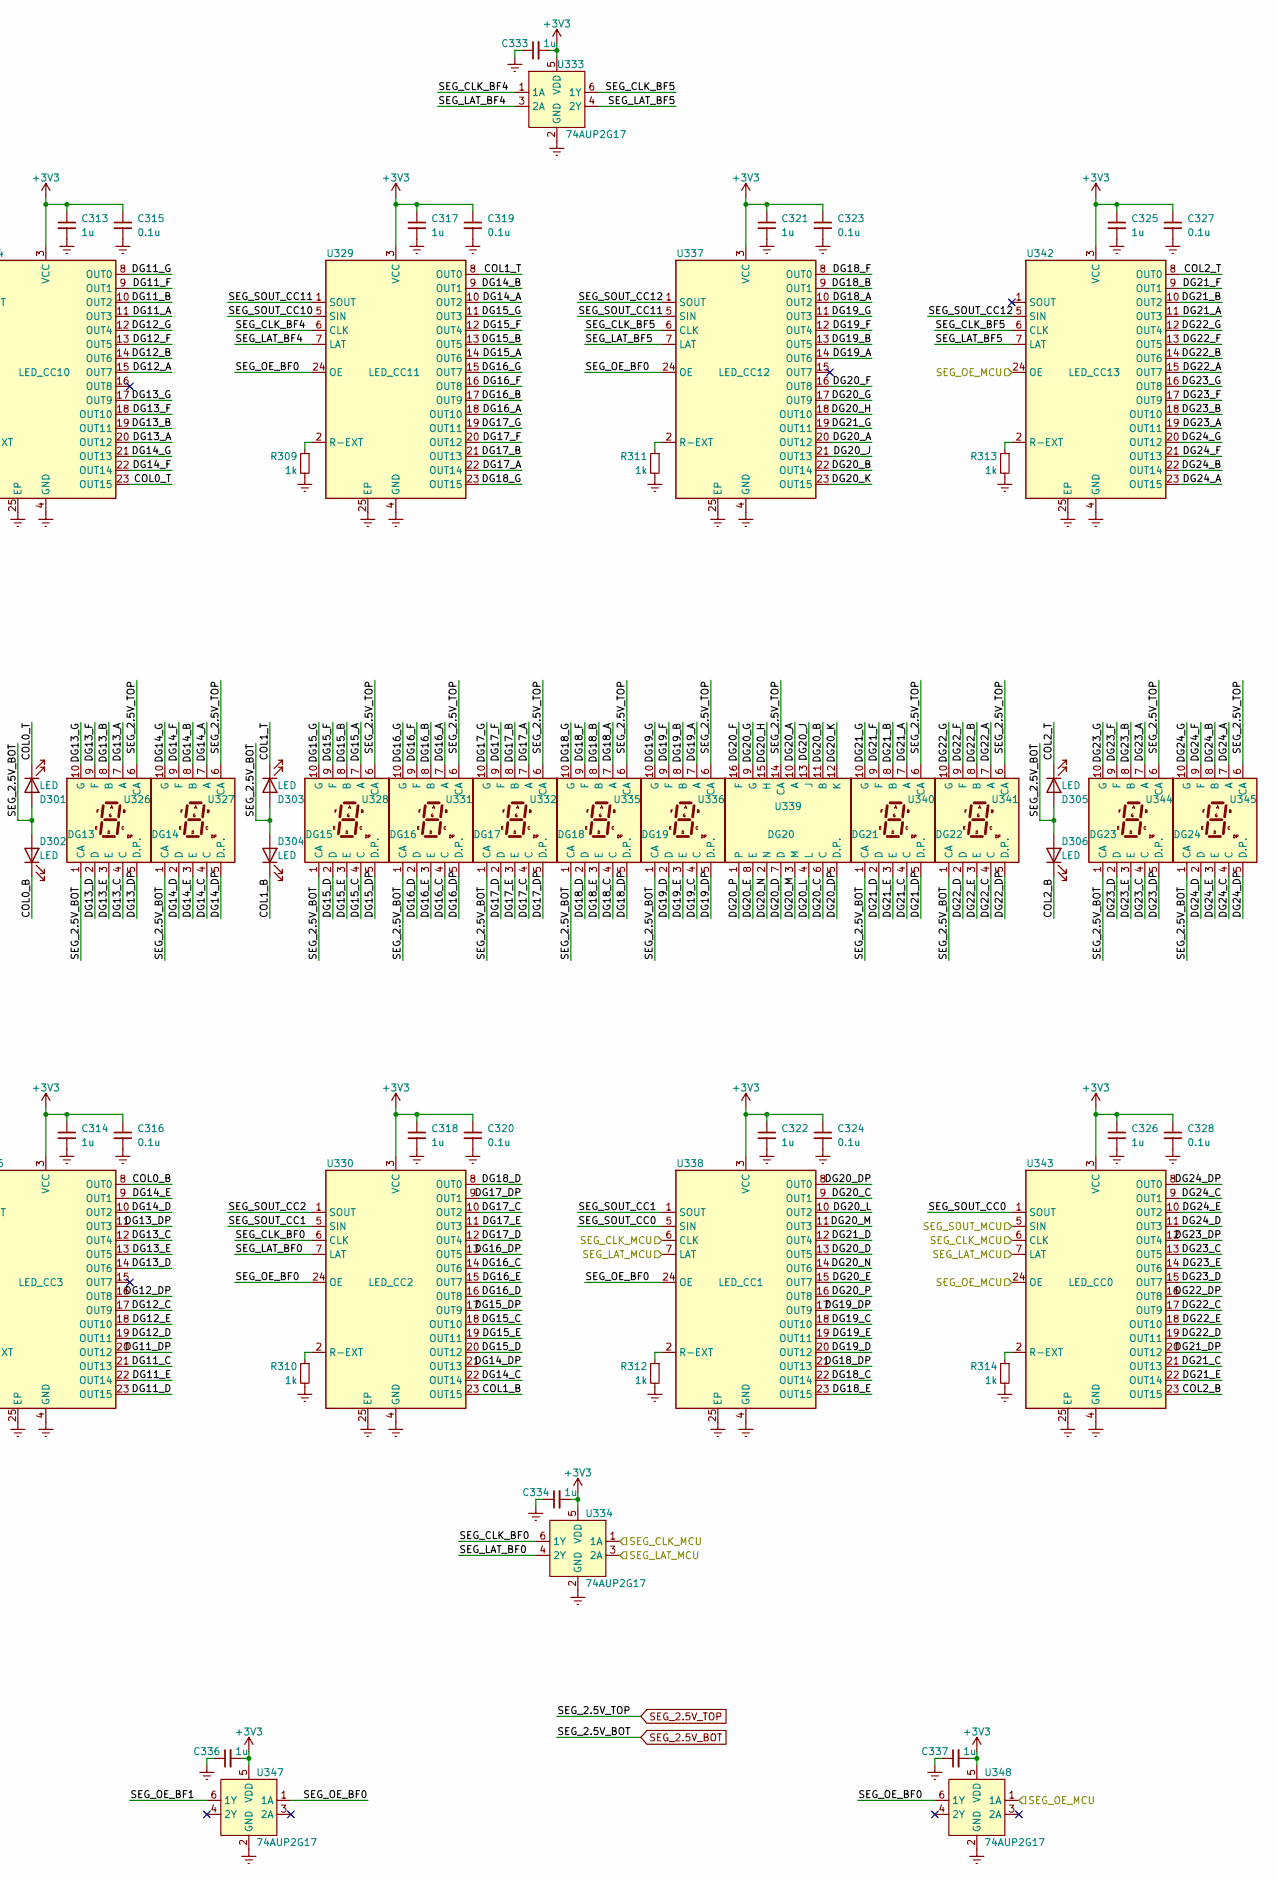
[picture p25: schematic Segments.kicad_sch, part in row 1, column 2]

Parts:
C301, C302, C305, C306, C309, C310, C313, C314, C317, C318, C321, C322, C325, C326, C329, C330, C331, C332, C333, C334, C335, C336, C337: 1u; C_0402_1005Metric
C303, C304, C307, C308, C311, C312, C315, C316, C319, C320, C323, C324, C327, C328: 0.1u; C_0402_1005Metric
D301, D302, D303, D304, D305, D306: LED; LED_0805_2012Metric
R301, R302, R303, R304, R305, R306, R307, R308, R309, R310, R311, R312, R313, R314: 1k; R_0402_1005Metric
U301: DG0; 7seg 0.8in smd
U302: DG1; 7seg 0.8in smd
U303: LED_CC7; QFN-24-1EP_4x4mm_P0.5mm_EP2.6x2.6mm
U304: LED_CC6; QFN-24-1EP_4x4mm_P0.5mm_EP2.6x2.6mm
U305: DG2; 7seg 0.8in smd
U306: DG3; 7seg 0.8in smd
U307, U308, U320, U322, U333, U334, U346, U347, U348: 74AUP2G17; XSON-6_SOT886
U309: DG4; 7seg 0.8in smd
U310: DG5; 7seg 0.8in smd
U311: LED_CC8; QFN-24-1EP_4x4mm_P0.5mm_EP2.6x2.6mm
U312: LED_CC5; QFN-24-1EP_4x4mm_P0.5mm_EP2.6x2.6mm
U313: DG6; 7seg 0.8in smd
U314: DG7; 7seg 0.8in smd
U315: DG8; 7seg 0.8in smd
U316: DG9; 7seg 0.8in smd
U317: LED_CC9; QFN-24-1EP_4x4mm_P0.5mm_EP2.6x2.6mm
U318: LED_CC4; QFN-24-1EP_4x4mm_P0.5mm_EP2.6x2.6mm
U319: DG10; 14seg 0.4in smd
U321: DG11; 7seg 0.8in smd
U323: DG12; 7seg 0.8in smd
U324: LED_CC10; QFN-24-1EP_4x4mm_P0.5mm_EP2.6x2.6mm
U325: LED_CC3; QFN-24-1EP_4x4mm_P0.5mm_EP2.6x2.6mm
U326: DG13; 7seg 0.8in smd
U327: DG14; 7seg 0.8in smd
U328: DG15; 7seg 0.8in smd
U329: LED_CC11; QFN-24-1EP_4x4mm_P0.5mm_EP2.6x2.6mm
U330: LED_CC2; QFN-24-1EP_4x4mm_P0.5mm_EP2.6x2.6mm
U331: DG16; 7seg 0.8in smd
U332: DG17; 7seg 0.8in smd
U335: DG18; 7seg 0.8in smd
U336: DG19; 7seg 0.8in smd
U337: LED_CC12; QFN-24-1EP_4x4mm_P0.5mm_EP2.6x2.6mm
U338: LED_CC1; QFN-24-1EP_4x4mm_P0.5mm_EP2.6x2.6mm
U339: DG20; 14seg 0.4in smd
U340: DG21; 7seg 0.8in smd
U341: DG22; 7seg 0.8in smd
U342: LED_CC13; QFN-24-1EP_4x4mm_P0.5mm_EP2.6x2.6mm
U343: LED_CC0; QFN-24-1EP_4x4mm_P0.5mm_EP2.6x2.6mm
U344: DG23; 7seg 0.8in smd
U345: DG24; 7seg 0.8in smd

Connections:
+3V3: C301.1, C302.1, C303.1, C304.1, C305.1, C306.1, C307.1, C308.1, C309.1, C310.1, C311.1, C312.1, C313.1, C314.1, C315.1, C316.1, C317.1, C318.1, C319.1, C320.1, C321.1, C322.1, C323.1, C324.1, C325.1, C326.1, C327.1, C328.1, C329.2, C330.2, C331.2, C332.2, C333.2, C334.2, C335.2, C336.2, C337.2, U303.3 (VCC), U304.3 (VCC), U307.5 (VDD), U308.5 (VDD), U311.3 (VCC), U312.3 (VCC), U317.3 (VCC), U318.3 (VCC), U320.5 (VDD), U322.5 (VDD), U324.3 (VCC), U325.3 (VCC), U329.3 (VCC), U330.3 (VCC), U333.5 (VDD), U334.5 (VDD), U337.3 (VCC), U338.3 (VCC), U342.3 (VCC), U343.3 (VCC), U346.5 (VDD), U347.5 (VDD), U348.5 (VDD); also elsewhere on the board
/SEG_CLK: U334.1 (1A), U338.6 (CLK), U343.6 (CLK); also elsewhere on the board
/SEG_LAT: U334.3 (2A), U338.7 (LAT), U343.7 (LAT); also elsewhere on the board
/SEG_MOSI: U343.5 (SIN); also elsewhere on the board
/SEG_OE: U342.24 (OE), U343.24 (OE), U348.1 (1A); also elsewhere on the board
/Segments/COL0_B: D302.1 (K), U325.8 (OUT0)
/Segments/COL0_T: D301.1 (K), U324.23 (OUT15)
/Segments/COL1_B: D304.1 (K), U330.23 (OUT15)
/Segments/COL1_T: D303.1 (K), U329.8 (OUT0)
/Segments/COL2_B: D306.1 (K), U343.23 (OUT15)
/Segments/COL2_T: D305.1 (K), U342.8 (OUT0)
/Segments/DG0_A: U301.7 (A), U303.11 (OUT3)
/Segments/DG0_B: U301.8 (B), U303.10 (OUT2)
/Segments/DG0_C: U301.4 (C), U304.21 (OUT13)
/Segments/DG0_D: U301.2 (D), U304.23 (OUT15)
/Segments/DG0_DP: U301.5 (D.P.), U304.20 (OUT12)
/Segments/DG0_E: U301.3 (E), U304.22 (OUT14)
/Segments/DG0_F: U301.9 (F), U303.9 (OUT1)
/Segments/DG0_G: U301.10 (G), U303.8 (OUT0)
/Segments/DG1_A: U302.7 (A), U303.15 (OUT7)
/Segments/DG1_B: U302.8 (B), U303.14 (OUT6)
/Segments/DG1_C: U302.4 (C), U304.17 (OUT9)
/Segments/DG1_D: U302.2 (D), U304.19 (OUT11)
/Segments/DG1_DP: U302.5 (D.P.), U304.16 (OUT8)
/Segments/DG1_E: U302.3 (E), U304.18 (OUT10)
/Segments/DG1_F: U302.9 (F), U303.13 (OUT5)
/Segments/DG1_G: U302.10 (G), U303.12 (OUT4)
/Segments/DG2_A: U303.19 (OUT11), U305.7 (A)
/Segments/DG2_B: U303.18 (OUT10), U305.8 (B)
/Segments/DG2_C: U304.13 (OUT5), U305.4 (C)
/Segments/DG2_D: U304.15 (OUT7), U305.2 (D)
/Segments/DG2_DP: U304.12 (OUT4), U305.5 (D.P.)
/Segments/DG2_E: U304.14 (OUT6), U305.3 (E)
/Segments/DG2_F: U303.17 (OUT9), U305.9 (F)
/Segments/DG2_G: U303.16 (OUT8), U305.10 (G)
/Segments/DG3_A: U303.23 (OUT15), U306.7 (A)
/Segments/DG3_B: U303.22 (OUT14), U306.8 (B)
/Segments/DG3_C: U304.9 (OUT1), U306.4 (C)
/Segments/DG3_D: U304.11 (OUT3), U306.2 (D)
/Segments/DG3_DP: U304.8 (OUT0), U306.5 (D.P.)
/Segments/DG3_E: U304.10 (OUT2), U306.3 (E)
/Segments/DG3_F: U303.21 (OUT13), U306.9 (F)
/Segments/DG3_G: U303.20 (OUT12), U306.10 (G)
/Segments/DG4_A: U309.7 (A), U311.11 (OUT3)
/Segments/DG4_B: U309.8 (B), U311.10 (OUT2)
/Segments/DG4_C: U309.4 (C), U312.21 (OUT13)
/Segments/DG4_D: U309.2 (D), U312.23 (OUT15)
/Segments/DG4_DP: U309.5 (D.P.), U312.20 (OUT12)
/Segments/DG4_E: U309.3 (E), U312.22 (OUT14)
/Segments/DG4_F: U309.9 (F), U311.9 (OUT1)
/Segments/DG4_G: U309.10 (G), U311.8 (OUT0)
/Segments/DG5_A: U310.7 (A), U311.15 (OUT7)
/Segments/DG5_B: U310.8 (B), U311.14 (OUT6)
/Segments/DG5_C: U310.4 (C), U312.17 (OUT9)
/Segments/DG5_D: U310.2 (D), U312.19 (OUT11)
/Segments/DG5_DP: U310.5 (D.P.), U312.16 (OUT8)
/Segments/DG5_E: U310.3 (E), U312.18 (OUT10)
/Segments/DG5_F: U310.9 (F), U311.13 (OUT5)
/Segments/DG5_G: U310.10 (G), U311.12 (OUT4)
/Segments/DG6_A: U311.19 (OUT11), U313.7 (A)
/Segments/DG6_B: U311.18 (OUT10), U313.8 (B)
/Segments/DG6_C: U312.13 (OUT5), U313.4 (C)
/Segments/DG6_D: U312.15 (OUT7), U313.2 (D)
/Segments/DG6_DP: U312.12 (OUT4), U313.5 (D.P.)
/Segments/DG6_E: U312.14 (OUT6), U313.3 (E)
/Segments/DG6_F: U311.17 (OUT9), U313.9 (F)
/Segments/DG6_G: U311.16 (OUT8), U313.10 (G)
/Segments/DG7_A: U311.23 (OUT15), U314.7 (A)
/Segments/DG7_B: U311.22 (OUT14), U314.8 (B)
/Segments/DG7_C: U312.9 (OUT1), U314.4 (C)
/Segments/DG7_D: U312.11 (OUT3), U314.2 (D)
/Segments/DG7_DP: U312.8 (OUT0), U314.5 (D.P.)
/Segments/DG7_E: U312.10 (OUT2), U314.3 (E)
/Segments/DG7_F: U311.21 (OUT13), U314.9 (F)
/Segments/DG7_G: U311.20 (OUT12), U314.10 (G)
/Segments/DG8_A: U315.7 (A), U317.11 (OUT3)
/Segments/DG8_B: U315.8 (B), U317.10 (OUT2)
/Segments/DG8_C: U315.4 (C), U318.21 (OUT13)
/Segments/DG8_D: U315.2 (D), U318.23 (OUT15)
/Segments/DG8_DP: U315.5 (D.P.), U318.20 (OUT12)
/Segments/DG8_E: U315.3 (E), U318.22 (OUT14)
/Segments/DG8_F: U315.9 (F), U317.9 (OUT1)
/Segments/DG8_G: U315.10 (G), U317.8 (OUT0)
/Segments/DG9_A: U316.7 (A), U317.15 (OUT7)
/Segments/DG9_B: U316.8 (B), U317.14 (OUT6)
/Segments/DG9_C: U316.4 (C), U318.17 (OUT9)
/Segments/DG9_D: U316.2 (D), U318.19 (OUT11)
/Segments/DG9_DP: U316.5 (D.P.), U318.16 (OUT8)
/Segments/DG9_E: U316.3 (E), U318.18 (OUT10)
/Segments/DG9_F: U316.9 (F), U317.13 (OUT5)
/Segments/DG9_G: U316.10 (G), U317.12 (OUT4)
/Segments/DG10_A: U317.20 (OUT12), U319.10 (A)
/Segments/DG10_B: U317.22 (OUT14), U319.11 (B)
/Segments/DG10_C: U318.9 (OUT1), U319.6 (C)
/Segments/DG10_D: U318.12 (OUT4), U319.7 (D)
/Segments/DG10_DP: U318.8 (OUT0), U319.5 (D.P.)
/Segments/DG10_E: U318.14 (OUT6), U319.8 (E)
/Segments/DG10_F: U317.16 (OUT8), U319.16 (F)
/Segments/DG10_G: U317.17 (OUT9), U319.9 (G)
/Segments/DG10_H: U317.18 (OUT10), U319.15 (H)
/Segments/DG10_J: U317.21 (OUT13), U319.13 (J)
/Segments/DG10_K: U317.23 (OUT15), U319.12 (K)
/Segments/DG10_L: U318.10 (OUT2), U319.4 (L)
/Segments/DG10_M: U318.11 (OUT3), U319.3 (M)
/Segments/DG10_N: U318.13 (OUT5), U319.2 (N)
/Segments/DG10_P: U318.15 (OUT7), U319.1
/Segments/DG11_A: U321.7 (A), U324.11 (OUT3)
/Segments/DG11_B: U321.8 (B), U324.10 (OUT2)
/Segments/DG11_C: U321.4 (C), U325.21 (OUT13)
/Segments/DG11_D: U321.2 (D), U325.23 (OUT15)
/Segments/DG11_DP: U321.5 (D.P.), U325.20 (OUT12)
/Segments/DG11_E: U321.3 (E), U325.22 (OUT14)
/Segments/DG11_F: U321.9 (F), U324.9 (OUT1)
/Segments/DG11_G: U321.10 (G), U324.8 (OUT0)
/Segments/DG12_A: U323.7 (A), U324.15 (OUT7)
/Segments/DG12_B: U323.8 (B), U324.14 (OUT6)
/Segments/DG12_C: U323.4 (C), U325.17 (OUT9)
/Segments/DG12_D: U323.2 (D), U325.19 (OUT11)
/Segments/DG12_DP: U323.5 (D.P.), U325.16 (OUT8)
/Segments/DG12_E: U323.3 (E), U325.18 (OUT10)
/Segments/DG12_F: U323.9 (F), U324.13 (OUT5)
/Segments/DG12_G: U323.10 (G), U324.12 (OUT4)
/Segments/DG13_A: U324.20 (OUT12), U326.7 (A)
/Segments/DG13_B: U324.19 (OUT11), U326.8 (B)
/Segments/DG13_C: U325.12 (OUT4), U326.4 (C)
/Segments/DG13_D: U325.14 (OUT6), U326.2 (D)
/Segments/DG13_DP: U325.11 (OUT3), U326.5 (D.P.)
/Segments/DG13_E: U325.13 (OUT5), U326.3 (E)
/Segments/DG13_F: U324.18 (OUT10), U326.9 (F)
/Segments/DG13_G: U324.17 (OUT9), U326.10 (G)
/Segments/DG14_A: U327.7 (A), U329.10 (OUT2)
/Segments/DG14_B: U327.8 (B), U329.9 (OUT1)
/Segments/DG14_C: U327.4 (C), U330.22 (OUT14)
/Segments/DG14_D: U325.10 (OUT2), U327.2 (D)
/Segments/DG14_DP: U327.5 (D.P.), U330.21 (OUT13)
/Segments/DG14_E: U325.9 (OUT1), U327.3 (E)
/Segments/DG14_F: U324.22 (OUT14), U327.9 (F)
/Segments/DG14_G: U324.21 (OUT13), U327.10 (G)
/Segments/DG15_A: U328.7 (A), U329.14 (OUT6)
/Segments/DG15_B: U328.8 (B), U329.13 (OUT5)
/Segments/DG15_C: U328.4 (C), U330.18 (OUT10)
/Segments/DG15_D: U328.2 (D), U330.20 (OUT12)
/Segments/DG15_DP: U328.5 (D.P.), U330.17 (OUT9)
/Segments/DG15_E: U328.3 (E), U330.19 (OUT11)
/Segments/DG15_F: U328.9 (F), U329.12 (OUT4)
/Segments/DG15_G: U328.10 (G), U329.11 (OUT3)
/Segments/DG16_A: U329.18 (OUT10), U331.7 (A)
/Segments/DG16_B: U329.17 (OUT9), U331.8 (B)
/Segments/DG16_C: U330.14 (OUT6), U331.4 (C)
/Segments/DG16_D: U330.16 (OUT8), U331.2 (D)
/Segments/DG16_DP: U330.13 (OUT5), U331.5 (D.P.)
/Segments/DG16_E: U330.15 (OUT7), U331.3 (E)
/Segments/DG16_F: U329.16 (OUT8), U331.9 (F)
/Segments/DG16_G: U329.15 (OUT7), U331.10 (G)
/Segments/DG17_A: U329.22 (OUT14), U332.7 (A)
/Segments/DG17_B: U329.21 (OUT13), U332.8 (B)
/Segments/DG17_C: U330.10 (OUT2), U332.4 (C)
/Segments/DG17_D: U330.12 (OUT4), U332.2 (D)
/Segments/DG17_DP: U330.9 (OUT1), U332.5 (D.P.)
/Segments/DG17_E: U330.11 (OUT3), U332.3 (E)
/Segments/DG17_F: U329.20 (OUT12), U332.9 (F)
/Segments/DG17_G: U329.19 (OUT11), U332.10 (G)
/Segments/DG18_A: U335.7 (A), U337.10 (OUT2)
/Segments/DG18_B: U335.8 (B), U337.9 (OUT1)
/Segments/DG18_C: U335.4 (C), U338.22 (OUT14)
/Segments/DG18_D: U330.8 (OUT0), U335.2 (D)
/Segments/DG18_DP: U335.5 (D.P.), U338.21 (OUT13)
/Segments/DG18_E: U335.3 (E), U338.23 (OUT15)
/Segments/DG18_F: U335.9 (F), U337.8 (OUT0)
/Segments/DG18_G: U329.23 (OUT15), U335.10 (G)
/Segments/DG19_A: U336.7 (A), U337.14 (OUT6)
/Segments/DG19_B: U336.8 (B), U337.13 (OUT5)
/Segments/DG19_C: U336.4 (C), U338.18 (OUT10)
/Segments/DG19_D: U336.2 (D), U338.20 (OUT12)
/Segments/DG19_DP: U336.5 (D.P.), U338.17 (OUT9)
/Segments/DG19_E: U336.3 (E), U338.19 (OUT11)
/Segments/DG19_F: U336.9 (F), U337.12 (OUT4)
/Segments/DG19_G: U336.10 (G), U337.11 (OUT3)
/Segments/DG20_A: U337.20 (OUT12), U339.10 (A)
/Segments/DG20_B: U337.22 (OUT14), U339.11 (B)
/Segments/DG20_C: U338.9 (OUT1), U339.6 (C)
/Segments/DG20_D: U338.13 (OUT5), U339.7 (D)
/Segments/DG20_DP: U338.8 (OUT0), U339.5 (D.P.)
/Segments/DG20_E: U338.15 (OUT7), U339.8 (E)
/Segments/DG20_F: U337.16 (OUT8), U339.16 (F)
/Segments/DG20_G: U337.17 (OUT9), U339.9 (G)
/Segments/DG20_H: U337.18 (OUT10), U339.15 (H)
/Segments/DG20_J: U337.21 (OUT13), U339.13 (J)
/Segments/DG20_K: U337.23 (OUT15), U339.12 (K)
/Segments/DG20_L: U338.10 (OUT2), U339.4 (L)
/Segments/DG20_M: U338.11 (OUT3), U339.3 (M)
/Segments/DG20_N: U338.14 (OUT6), U339.2 (N)
/Segments/DG20_P: U338.16 (OUT8), U339.1
/Segments/DG21_A: U340.7 (A), U342.11 (OUT3)
/Segments/DG21_B: U340.8 (B), U342.10 (OUT2)
/Segments/DG21_C: U340.4 (C), U343.21 (OUT13)
/Segments/DG21_D: U338.12 (OUT4), U340.2 (D)
/Segments/DG21_DP: U340.5 (D.P.), U343.20 (OUT12)
/Segments/DG21_E: U340.3 (E), U343.22 (OUT14)
/Segments/DG21_F: U340.9 (F), U342.9 (OUT1)
/Segments/DG21_G: U337.19 (OUT11), U340.10 (G)
/Segments/DG22_A: U341.7 (A), U342.15 (OUT7)
/Segments/DG22_B: U341.8 (B), U342.14 (OUT6)
/Segments/DG22_C: U341.4 (C), U343.17 (OUT9)
/Segments/DG22_D: U341.2 (D), U343.19 (OUT11)
/Segments/DG22_DP: U341.5 (D.P.), U343.16 (OUT8)
/Segments/DG22_E: U341.3 (E), U343.18 (OUT10)
/Segments/DG22_F: U341.9 (F), U342.13 (OUT5)
/Segments/DG22_G: U341.10 (G), U342.12 (OUT4)
/Segments/DG23_A: U342.19 (OUT11), U344.7 (A)
/Segments/DG23_B: U342.18 (OUT10), U344.8 (B)
/Segments/DG23_C: U343.13 (OUT5), U344.4 (C)
/Segments/DG23_D: U343.15 (OUT7), U344.2 (D)
/Segments/DG23_DP: U343.12 (OUT4), U344.5 (D.P.)
/Segments/DG23_E: U343.14 (OUT6), U344.3 (E)
/Segments/DG23_F: U342.17 (OUT9), U344.9 (F)
/Segments/DG23_G: U342.16 (OUT8), U344.10 (G)
/Segments/DG24_A: U342.23 (OUT15), U345.7 (A)
/Segments/DG24_B: U342.22 (OUT14), U345.8 (B)
/Segments/DG24_C: U343.9 (OUT1), U345.4 (C)
/Segments/DG24_D: U343.11 (OUT3), U345.2 (D)
/Segments/DG24_DP: U343.8 (OUT0), U345.5 (D.P.)
/Segments/DG24_E: U343.10 (OUT2), U345.3 (E)
/Segments/DG24_F: U342.21 (OUT13), U345.9 (F)
/Segments/DG24_G: U342.20 (OUT12), U345.10 (G)
/Segments/SEG_CLK_BF0: U320.1 (1A), U325.6 (CLK), U330.6 (CLK), U334.6 (1Y)
/Segments/SEG_CLK_BF1: U307.1 (1A), U312.6 (CLK), U318.6 (CLK), U320.6 (1Y)
/Segments/SEG_CLK_BF2: U303.6 (CLK), U304.6 (CLK), U307.6 (1Y), U308.1 (1A)
/Segments/SEG_CLK_BF3: U308.6 (1Y), U311.6 (CLK), U317.6 (CLK), U322.1 (1A)
/Segments/SEG_CLK_BF4: U322.6 (1Y), U324.6 (CLK), U329.6 (CLK), U333.1 (1A)
/Segments/SEG_CLK_BF5: U333.6 (1Y), U337.6 (CLK), U342.6 (CLK)
/Segments/SEG_LAT_BF0: U320.3 (2A), U325.7 (LAT), U330.7 (LAT), U334.4 (2Y)
/Segments/SEG_LAT_BF1: U307.3 (2A), U312.7 (LAT), U318.7 (LAT), U320.4 (2Y)
/Segments/SEG_LAT_BF2: U303.7 (LAT), U304.7 (LAT), U307.4 (2Y), U308.3 (2A)
/Segments/SEG_LAT_BF3: U308.4 (2Y), U311.7 (LAT), U317.7 (LAT), U322.3 (2A)
/Segments/SEG_LAT_BF4: U322.4 (2Y), U324.7 (LAT), U329.7 (LAT), U333.3 (2A)
/Segments/SEG_LAT_BF5: U333.4 (2Y), U337.7 (LAT), U342.7 (LAT)
/Segments/SEG_OE_BF0: U329.24 (OE), U330.24 (OE), U337.24 (OE), U338.24 (OE), U347.1 (1A), U348.6 (1Y)
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

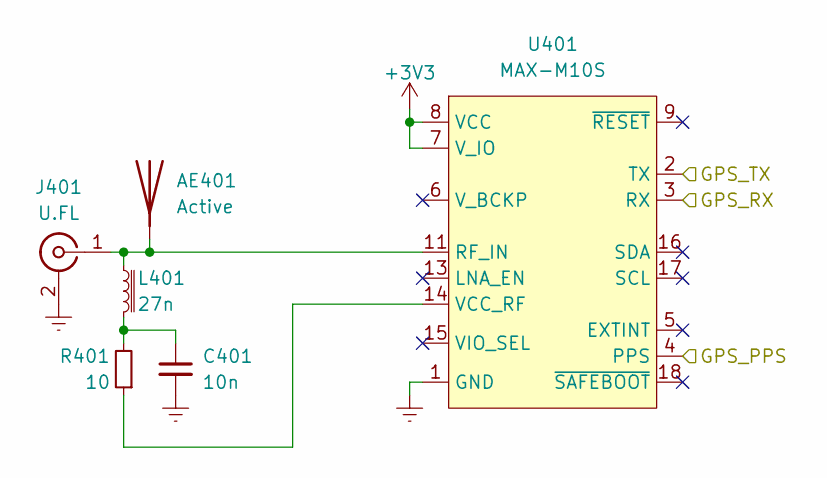
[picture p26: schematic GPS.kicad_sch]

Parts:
AE401: Active
C401: 10n; C_0402_1005Metric
J401: U.FL; U.FL_Hirose_U.FL-R-SMT-1_Vertical
L401: 27n; L_0402_1005Metric
R401: 10; R_0402_1005Metric
U401: MAX-M10S; UBLOX_MAX-M10S

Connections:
+3V3: U401.7 (V_IO), U401.8 (VCC); also elsewhere on the board
/GPS_PPS: U401.4 (PPS); also elsewhere on the board
/GPS_RX: U401.3 (RX); also elsewhere on the board
/GPS_TX: U401.2 (TX); also elsewhere on the board
Earth: C401.2, J401.2 (Ext), U401.1 (GND), U401.10 (GND), U401.12 (GND); also elsewhere on the board
unnamed: AE401.1, J401.1 (In), L401.1, U401.11 (RF_IN)
unnamed: C401.1, L401.2, R401.2
unnamed: R401.1, U401.14 (VCC_RF)

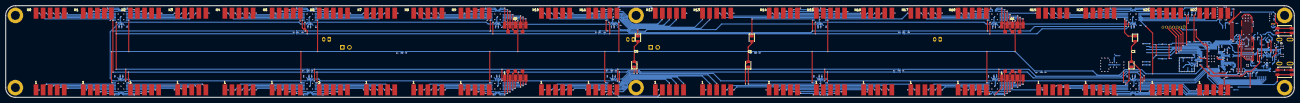
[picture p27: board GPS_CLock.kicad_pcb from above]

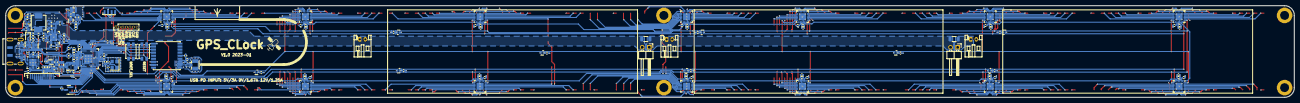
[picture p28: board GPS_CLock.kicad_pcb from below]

Board: 4 copper layers, 464.0 x 33.0 mm, 209 parts (170 on the bottom side), 343 nets.

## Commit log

2022-12-29 rename kicad project files
    [GPS_CLock.kicad_pcb, GPS_CLock.kicad_sch, Power.kicad_sch]
2022-12-29 update pcb
2022-12-31 change to larger segments
    [Display.kicad_sch, GPS.kicad_sch, GPS_CLock.kicad_pcb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]
2022-12-31 add schematic plot
2023-01-03 updated pcb
    [Display.kicad_sch, GPS_CLock.kicad_pcb, GPS_CLock.kicad_sch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]
